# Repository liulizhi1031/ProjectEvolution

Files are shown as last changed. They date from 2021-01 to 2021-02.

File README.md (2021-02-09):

# ProjectEvolution
## 一款航模/无人机/机器人遥控器  
## A RC/Drone/Robot Controler   

### 一.项目进展

#### &emsp;2021年2月9日

&emsp;目前本项目已完成初版PCB和外壳设计，马上开始软件开发阶段。（为了节省材料，外壳有点惨不忍睹，，，，）

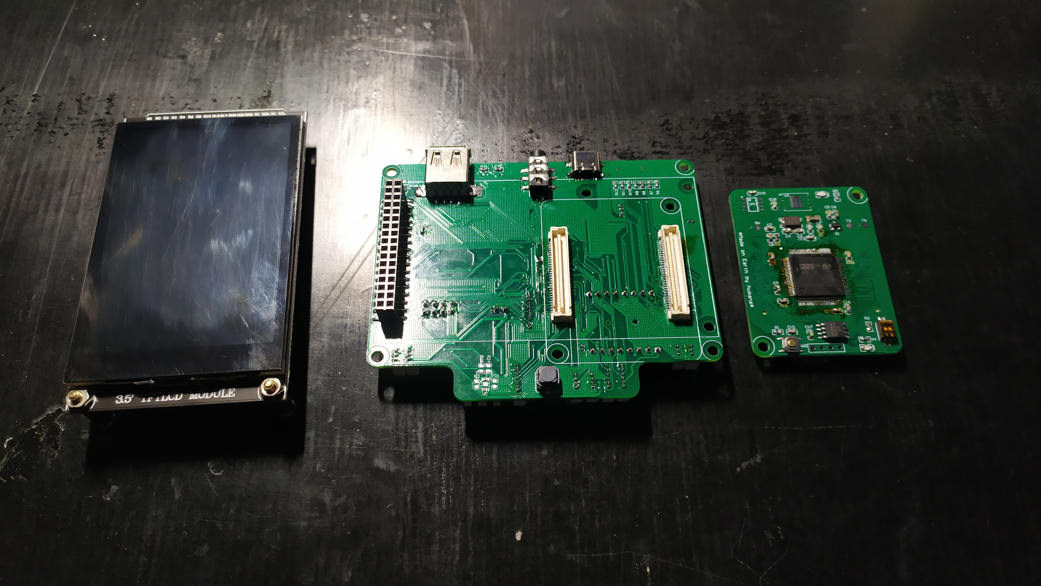
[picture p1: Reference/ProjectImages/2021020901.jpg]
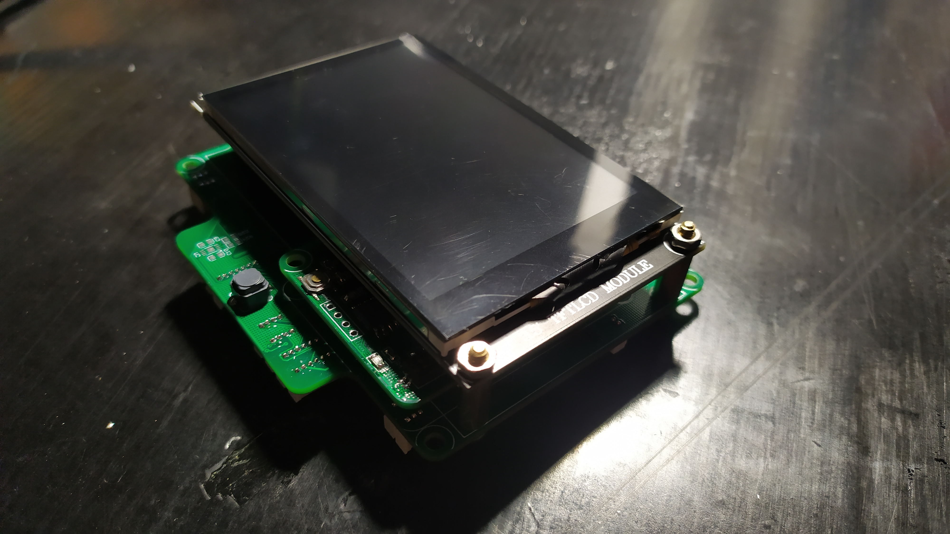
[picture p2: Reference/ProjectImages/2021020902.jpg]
 

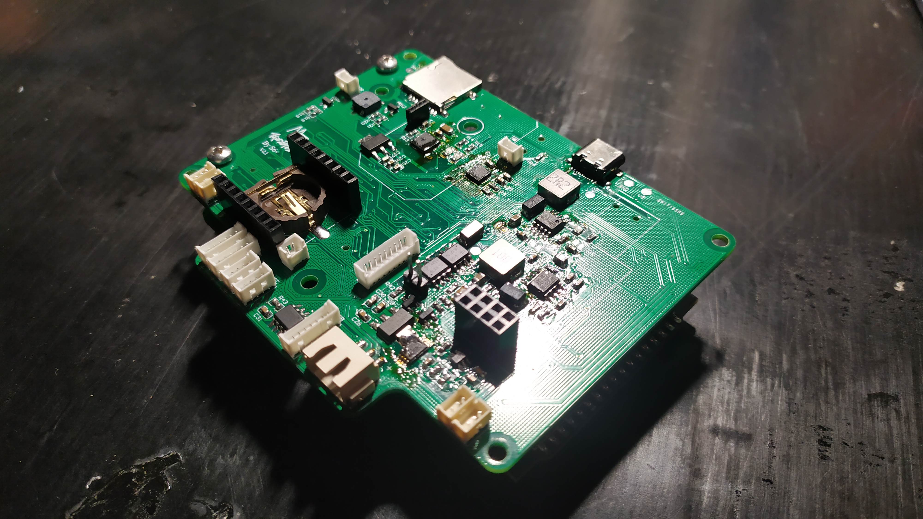
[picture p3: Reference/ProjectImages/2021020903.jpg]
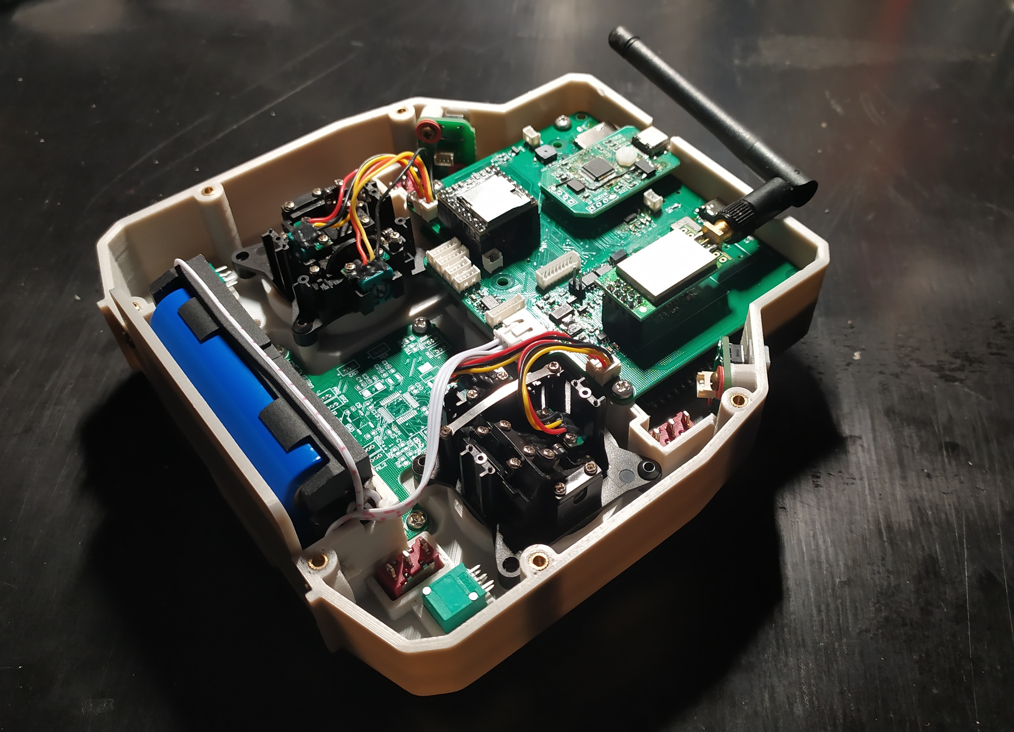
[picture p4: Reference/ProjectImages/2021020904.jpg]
 

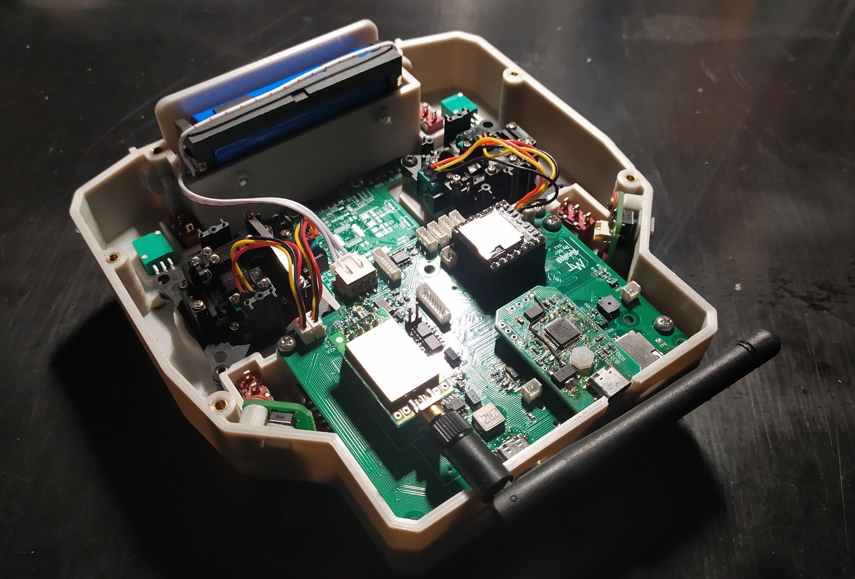
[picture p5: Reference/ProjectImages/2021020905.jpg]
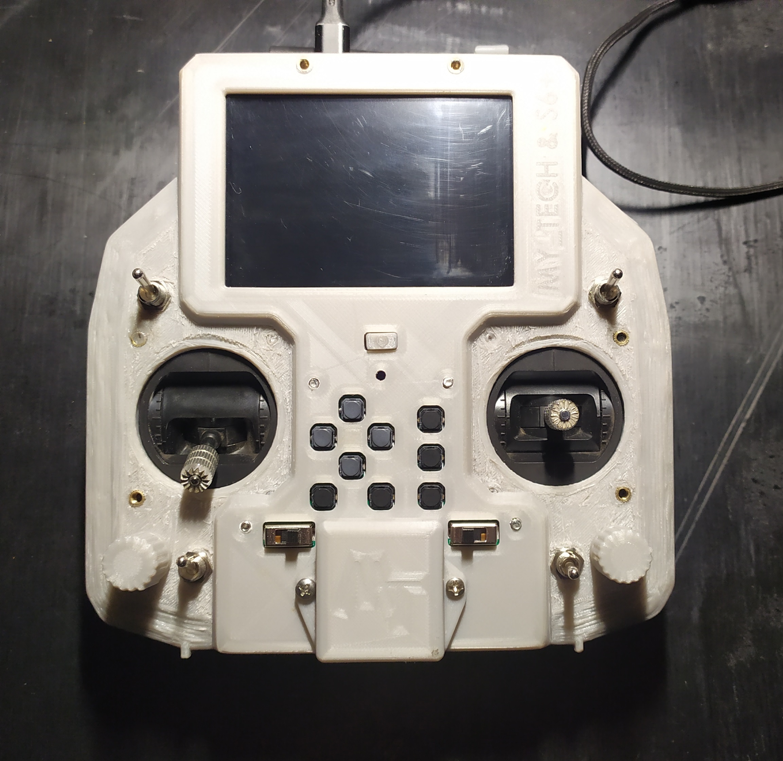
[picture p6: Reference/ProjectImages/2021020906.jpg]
 

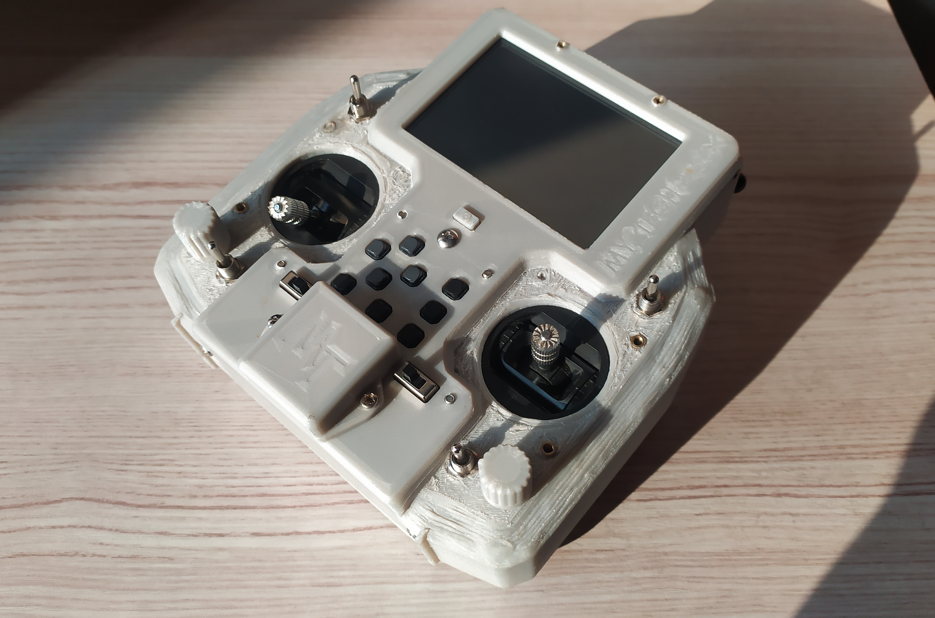
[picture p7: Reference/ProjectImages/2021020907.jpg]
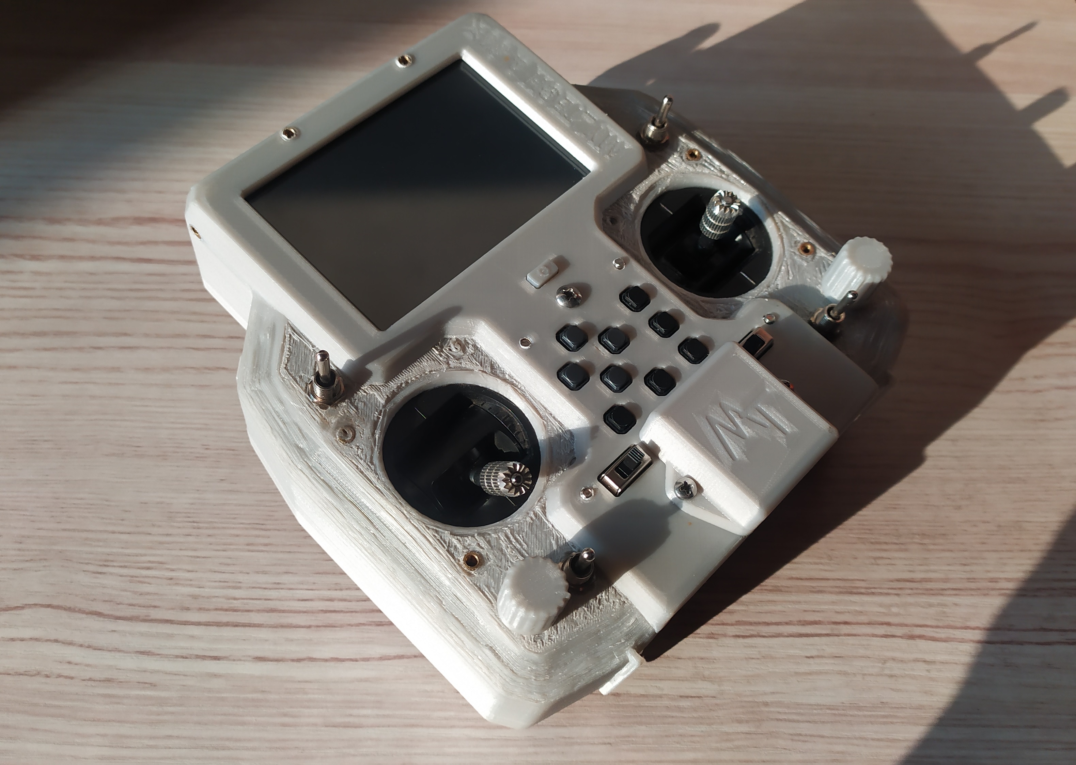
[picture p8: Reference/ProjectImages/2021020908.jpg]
 

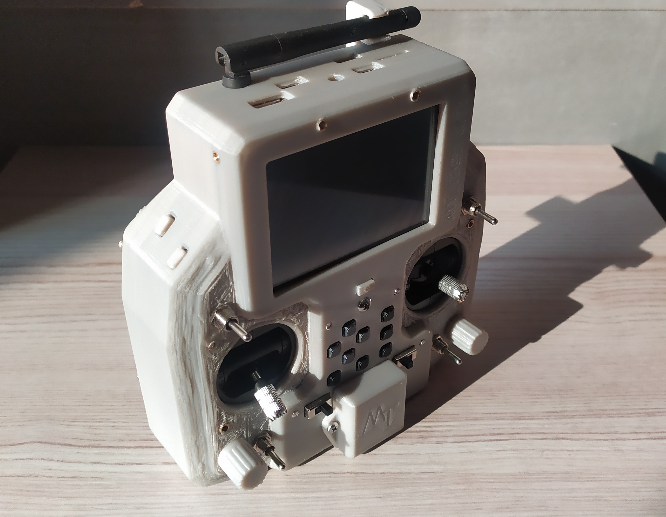
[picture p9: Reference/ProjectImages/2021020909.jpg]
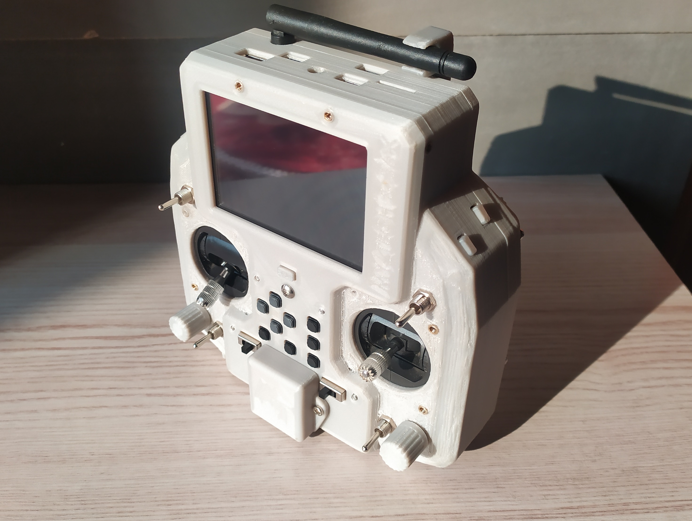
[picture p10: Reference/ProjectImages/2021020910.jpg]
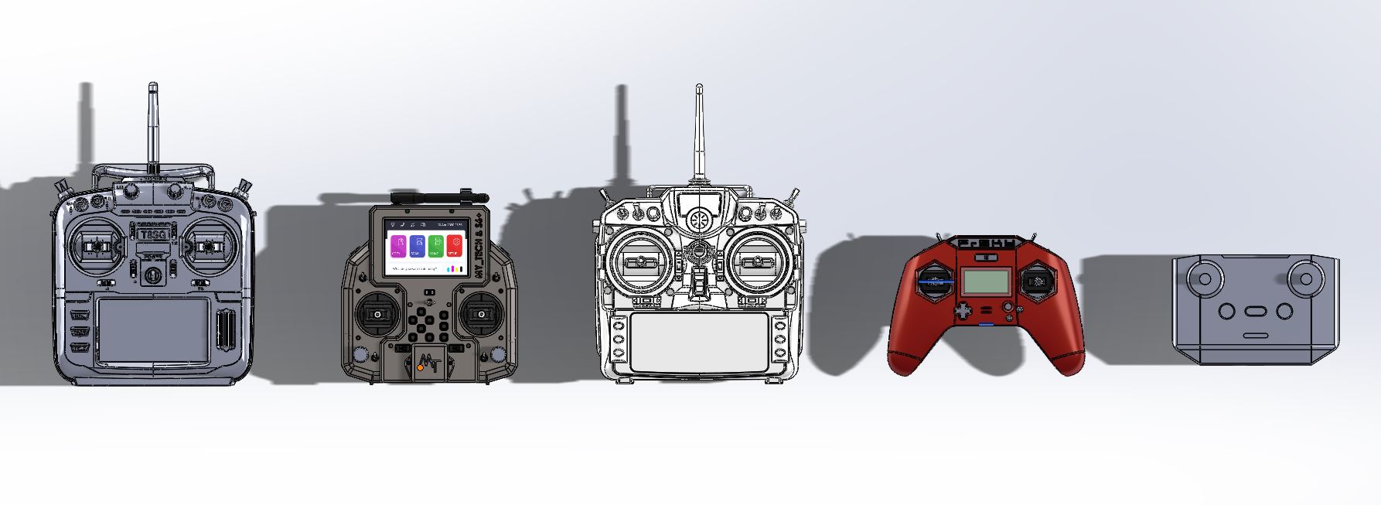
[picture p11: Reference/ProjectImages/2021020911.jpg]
 

### 二.项目简介

&emsp;本项目起始于2020年底，但追溯起来，我个人自制遥控器可以一直延伸到2016年左右。2015年由于资金和安全等原因，我放弃了自制火箭项目，转而玩多旋翼无人机，当时的大疆还是一颗争议不断的新星，Doby无人机正在火热众筹，我正即将从高中毕业，也正在自学Arduino。相比火箭，多旋翼使用成本几乎可以忽略不计，安全性也大大提高，但放在我眼前的第一件事就是遥控器的选择。  
&emsp;多旋翼无人机是从航模的基础上发展而来技术，因此当时大多数自制无人机也都采用成品航模遥控器，然而对于一个四线城市的农村高中生来说，即使是富斯i6也让我觉得太贵了，更何况越是便宜的遥控器，功能就越简陋，更难以让我这个轻度强迫症患者接受。既然好的买不起，买得起的又太渣，那干脆就自己做吧。我没有想到的是这个坑到现在我还没有填上，，，，，  
&emsp;我的第一套自制的遥控系统是在2016年暑假完成的，样子相当简陋，但还是用了模块化的设计，主控是Arduino nano，遥控器分为左右摇杆模块、显示模块、核心模块，可以组合成极简模式和完全体模式。     

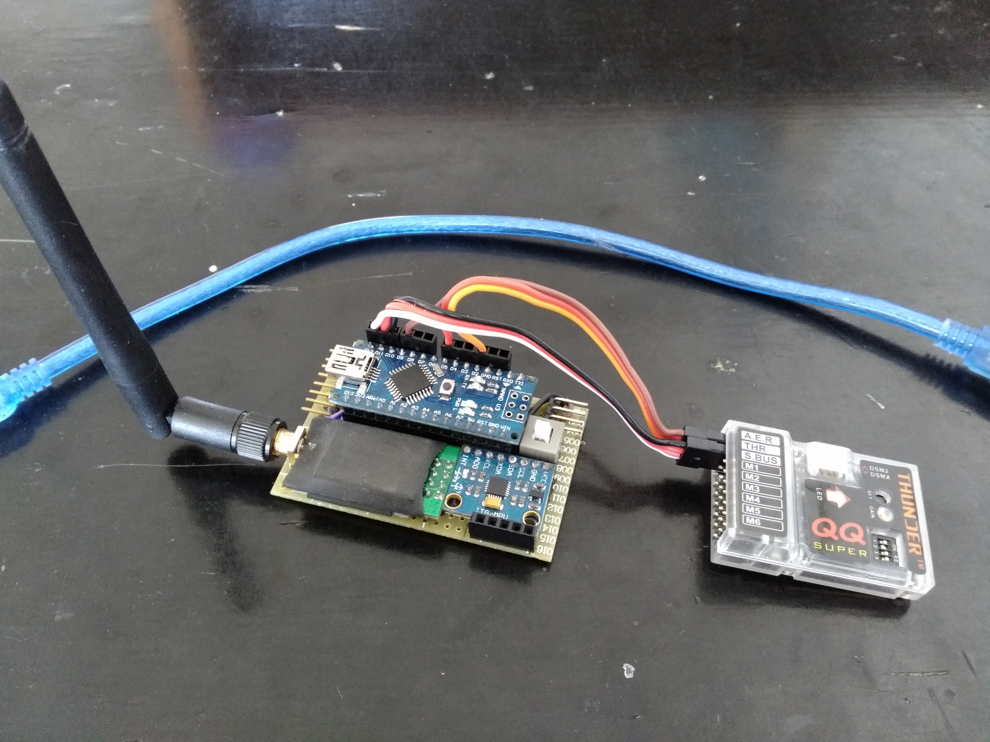
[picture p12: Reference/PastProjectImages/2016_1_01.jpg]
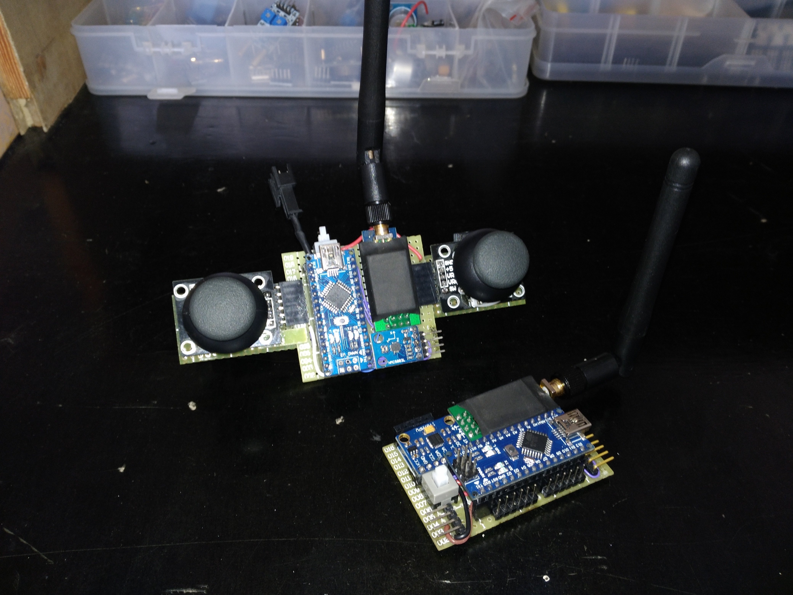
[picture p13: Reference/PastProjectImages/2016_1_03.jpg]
 

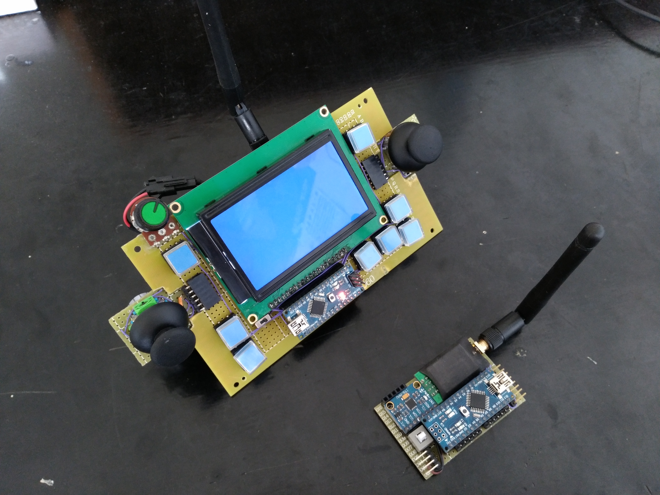
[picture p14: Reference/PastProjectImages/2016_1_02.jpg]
 

 &emsp;2016年9月，我进入河北科技大学，成为飞行器设计与工程专业的首批学生，一个月以后我加入了电气学院409实验室（大学生创新素能基地）接着填我的坑。我使用了3块Arduino nano以满足功能需要，分别负责显示、数据读取、通信和数据处理。然而结果是惨烈的，Arduino孱弱的性能根本无法支撑如此的野心，只有STM32才能救项目！      

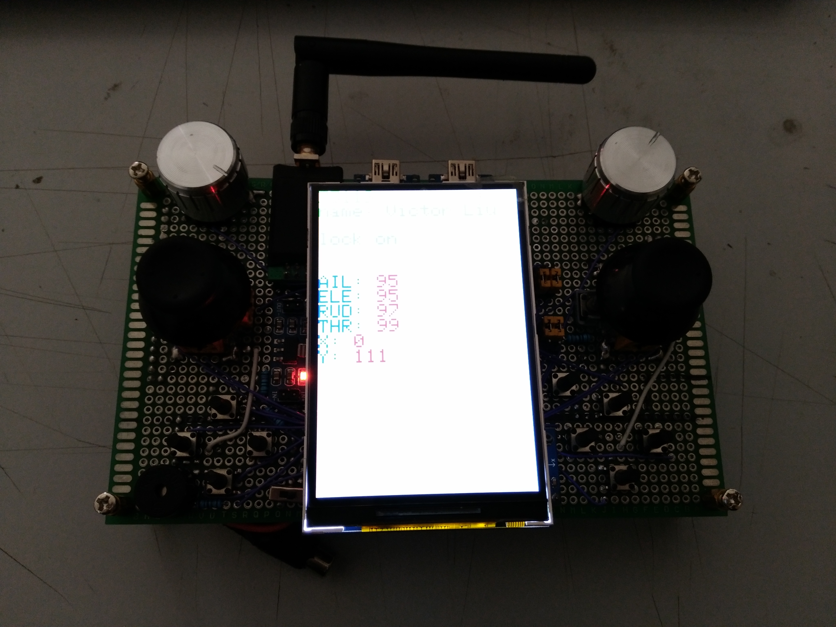
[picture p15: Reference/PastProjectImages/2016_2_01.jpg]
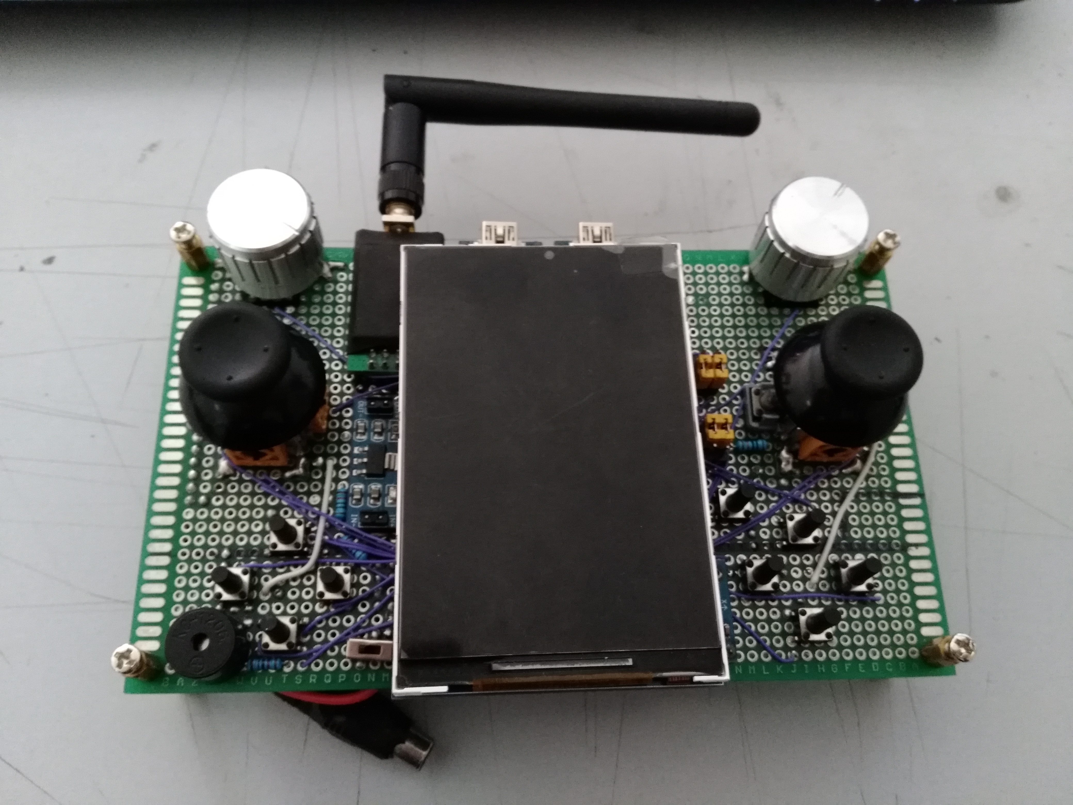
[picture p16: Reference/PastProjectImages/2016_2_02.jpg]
 

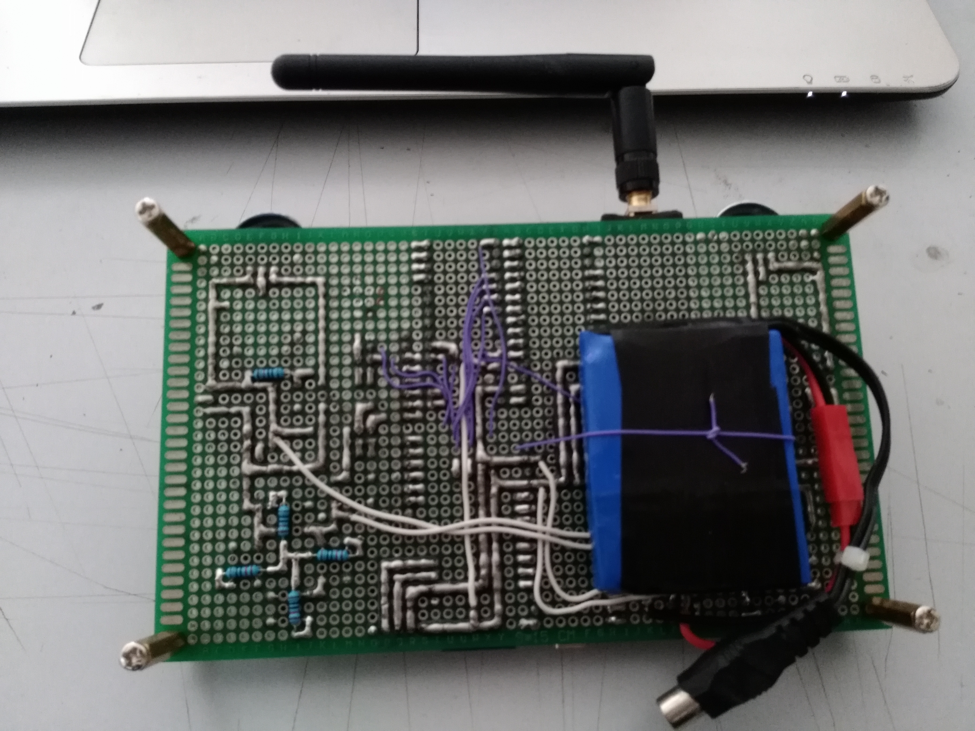
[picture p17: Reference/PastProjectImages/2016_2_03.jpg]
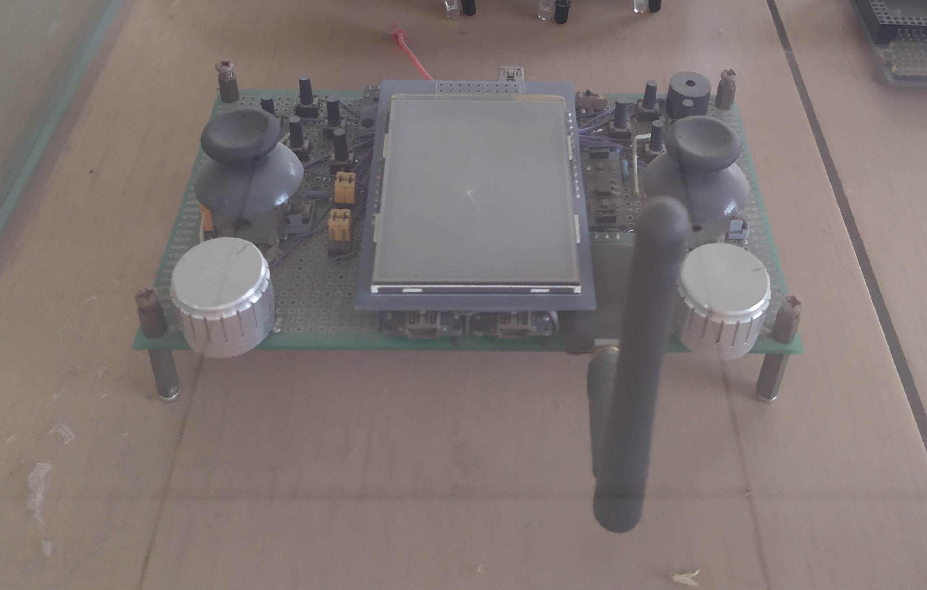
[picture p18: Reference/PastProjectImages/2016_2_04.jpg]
  

&emsp;接下来开始学习研究STM32，我发现F1和F4的学习难度几乎相同，因而直接上到STM32F407VET6，屏幕使用电阻触摸屏，然而做到一半我发现我的板子被焊成了假发，密密麻麻的飞线无不触发我的强迫症，因此学习PCB绘制看来是下一个必须解决的问题。    

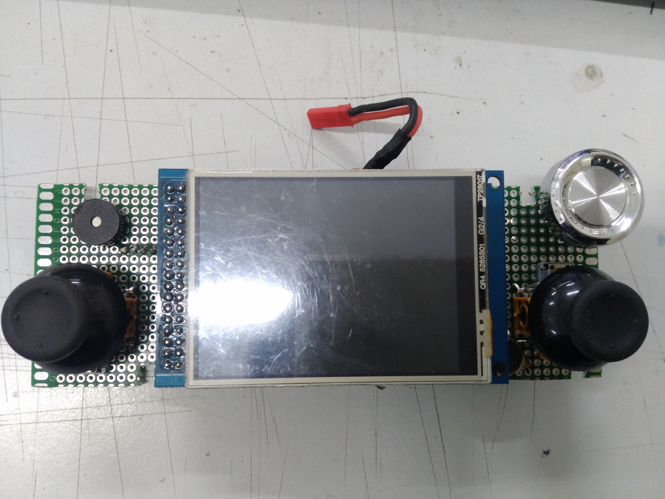
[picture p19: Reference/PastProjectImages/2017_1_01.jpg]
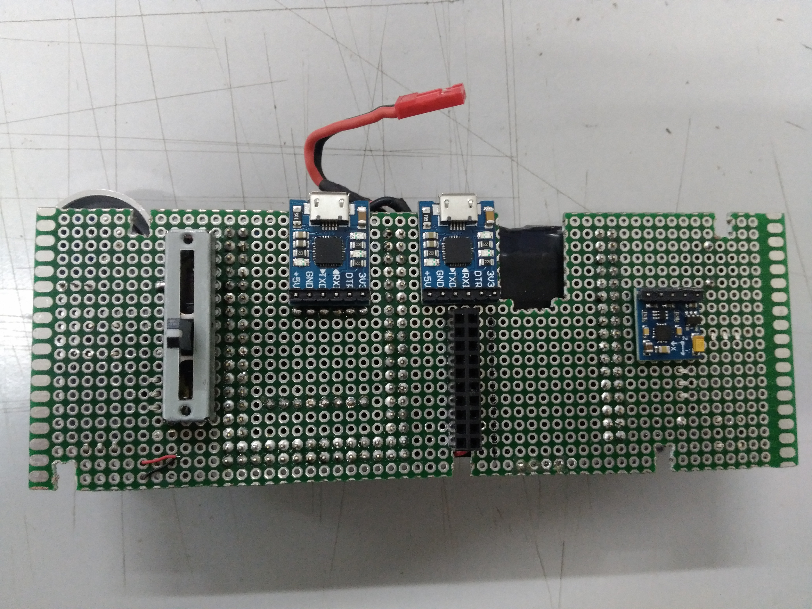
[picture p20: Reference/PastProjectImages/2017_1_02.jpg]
  

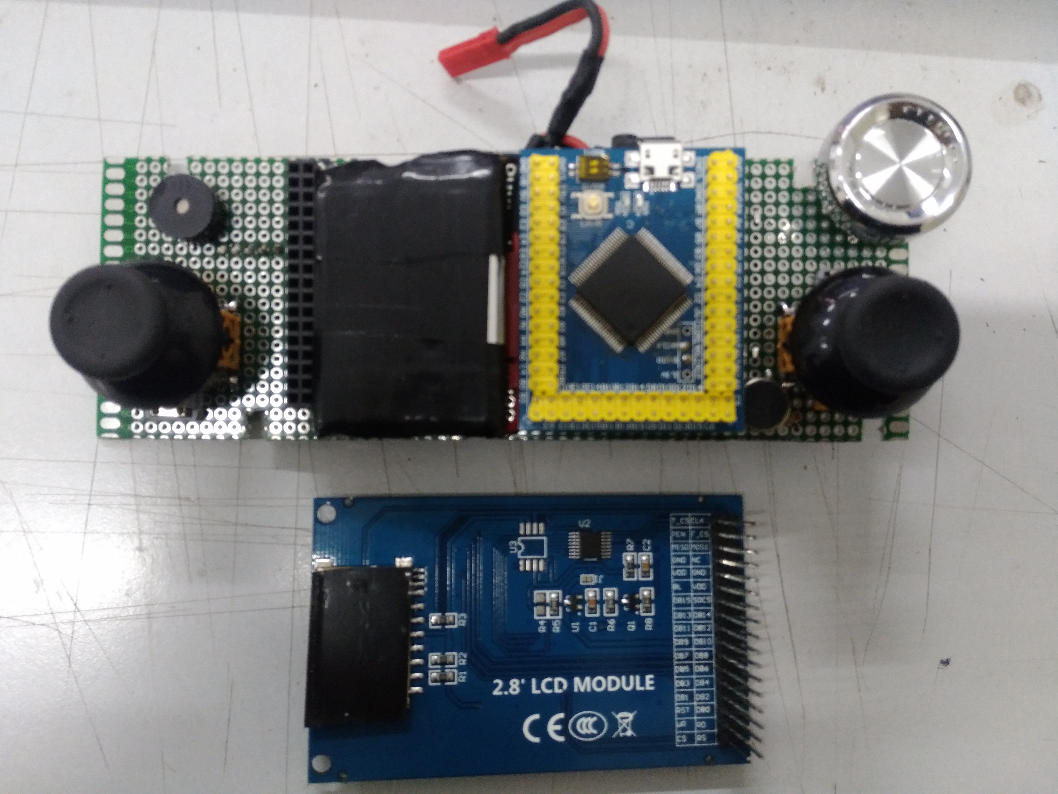
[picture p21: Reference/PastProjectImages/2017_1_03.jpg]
 

&emsp;与此同时我申报了大学生创新训练项目，虽然只拿到了校级，但顺便拿个名头也还不错了。由于此时我还在航模协会摸鱼，因此也学到了CAD和SolidWorks，接下来就是用STM32、AD、CAD来给这个项目做个了断了。虽然项目结了题，但是我对这套硬件并不满意，亚克力的外壳极为脆弱又搁手，体积虽然比我当时用的AT9小的多，但显然我馋了刚刚发布的大疆Mavic遥控器的身子，因此我又开启了新的征途。    

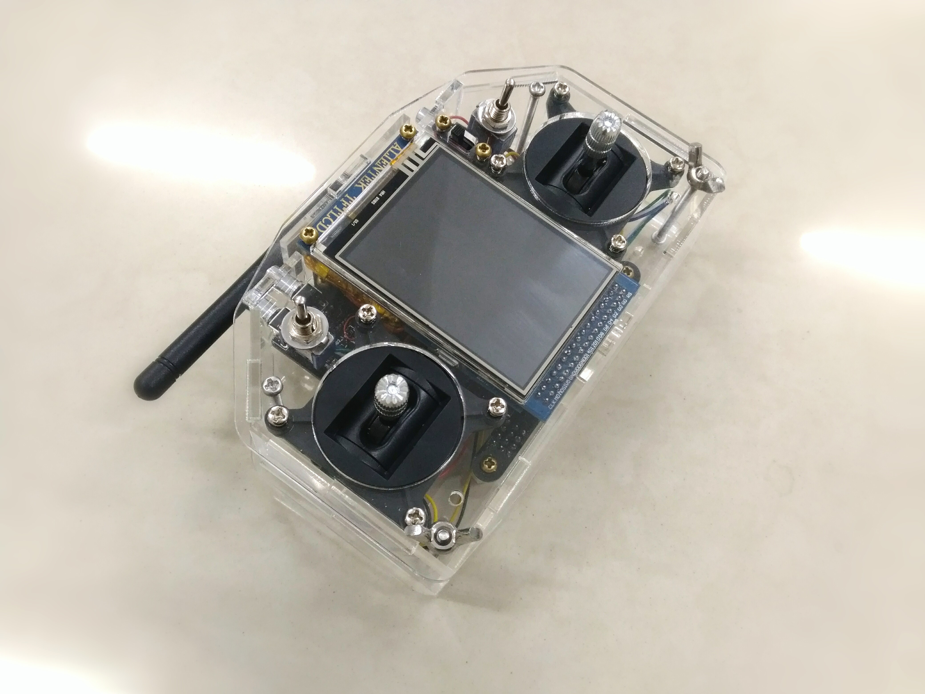
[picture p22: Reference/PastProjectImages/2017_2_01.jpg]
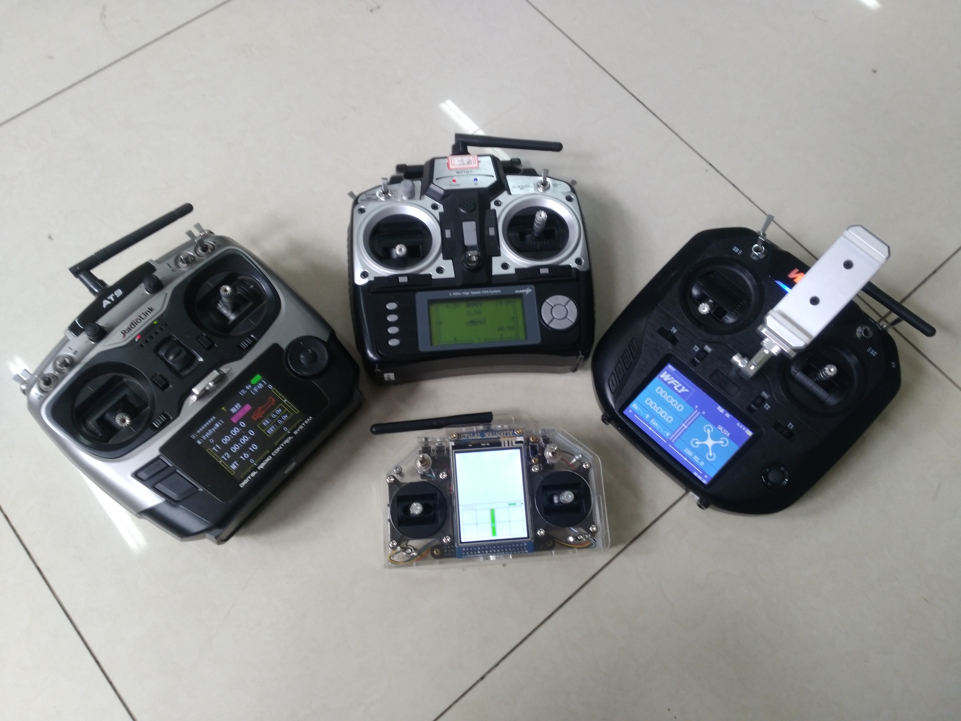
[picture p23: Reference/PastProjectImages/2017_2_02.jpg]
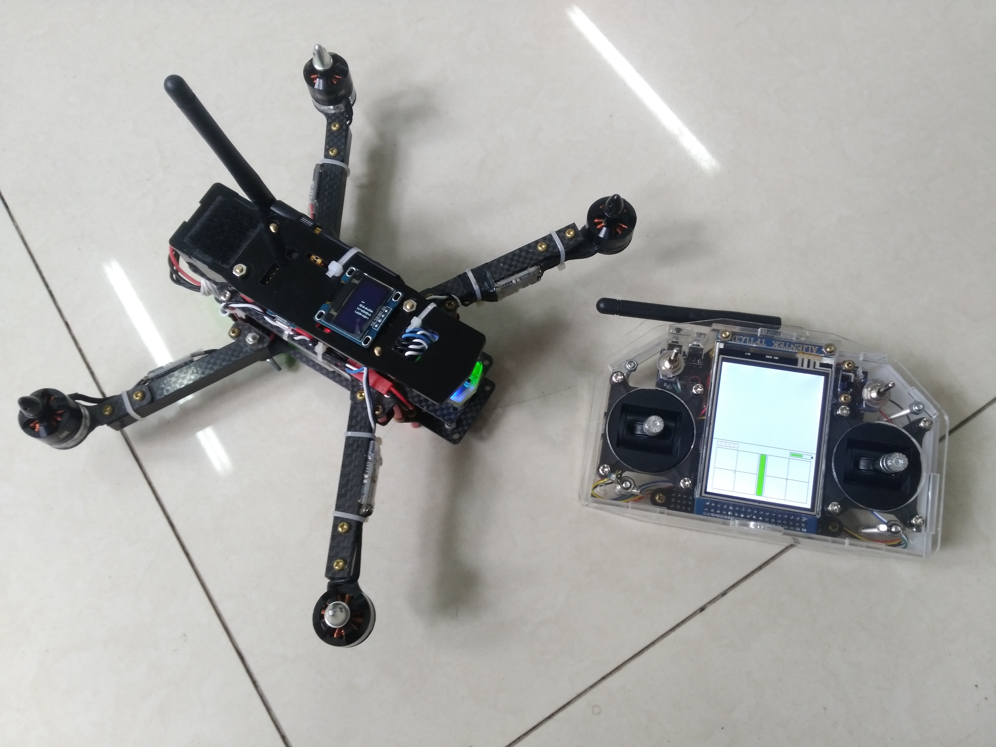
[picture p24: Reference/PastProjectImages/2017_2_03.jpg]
   

&emsp;这次为了更加紧凑，使用了游戏机摇杆（这显然是个致命缺陷），主控STM32F405RGT6直接贴在PCB上，屏幕也缩水到1.8寸（又一个致命缺陷）。一个偶然的机会我发现网上的3D打印服务还不错，而实验室申请的3D打印机一直久批不下，因而只能从网上找平台了，不得不说，光固化真香。总的来看，此时的遥控器和最初的遥控器早已天差地别，但距离成品和我的预期还差的远。    

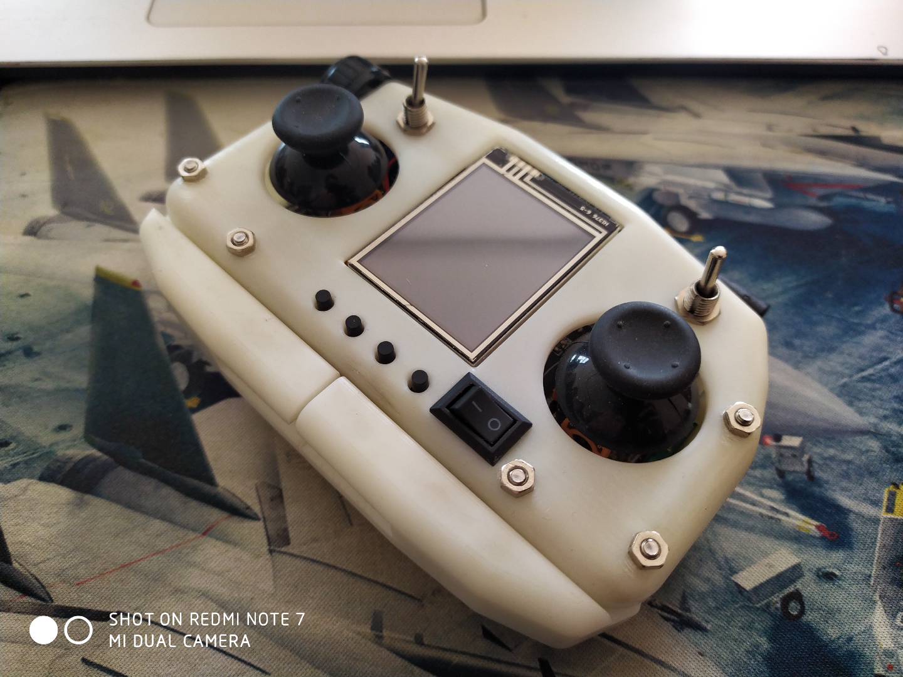
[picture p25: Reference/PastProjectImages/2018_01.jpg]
 

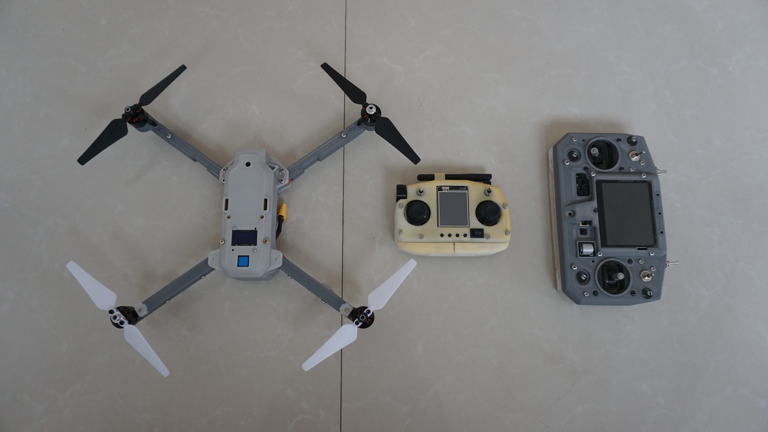
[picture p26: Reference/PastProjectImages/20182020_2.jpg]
&emsp;接下来的一年就是准备考研，但显然我高估了自己对考试的忍耐程度，直到2020年初，打着毕设的幌子，我重新开始填坑，这次希望能让遥控器更加成熟吧。毕设的进度催促着我要把重心向着多旋翼端偏移，这个控也仅仅完成了硬件的初步设计，软件更是只建了个文件夹。当然暴露的问题也不少，包括由于屏幕中置使遥控器过宽、过于集中化的PCB设计使试错成本猛增、握持手感极差等等一系列细节问题。    

&emsp;时间来到现在，2020年我一直在准备考研二战，一年的闭关修炼差点直接把我送走，还好这一切都在它该结束的时刻结束了。虽然考试凉了，但坑还是要接着填啊。为了方便和志同道合的朋友们交流心德，也是为了督促自己减少去安东星摸鱼的时间，我决定把项目公开出来。后排提醒，PCB线布的贼乱、代码bug更多，大佬轻喷。  
&emsp;目前项目取名为“进化”，计划使用STM32H750VBT6作为主控（性价比高），STM32F103C8T6作为协处理器（主控IO太少），3.5寸电容触摸屏（性价比高），固件基于FreeRTOS（文件夹还没建），界面基于LVGL，兼容主流航模遥控器高频头，自带通信模块仍是NRF24L01，但预留扩展接口，稍微遗憾的是由于H750的IO太少，音乐播放只能使用独立的MP3模块，但也降低了开发难度，算是一个取舍吧。  
&emsp;目前项目正在进行中，感兴趣的朋友们欢迎持续关注，可以关注我的bilibili账号“我的科技工作室”交流。 20210128

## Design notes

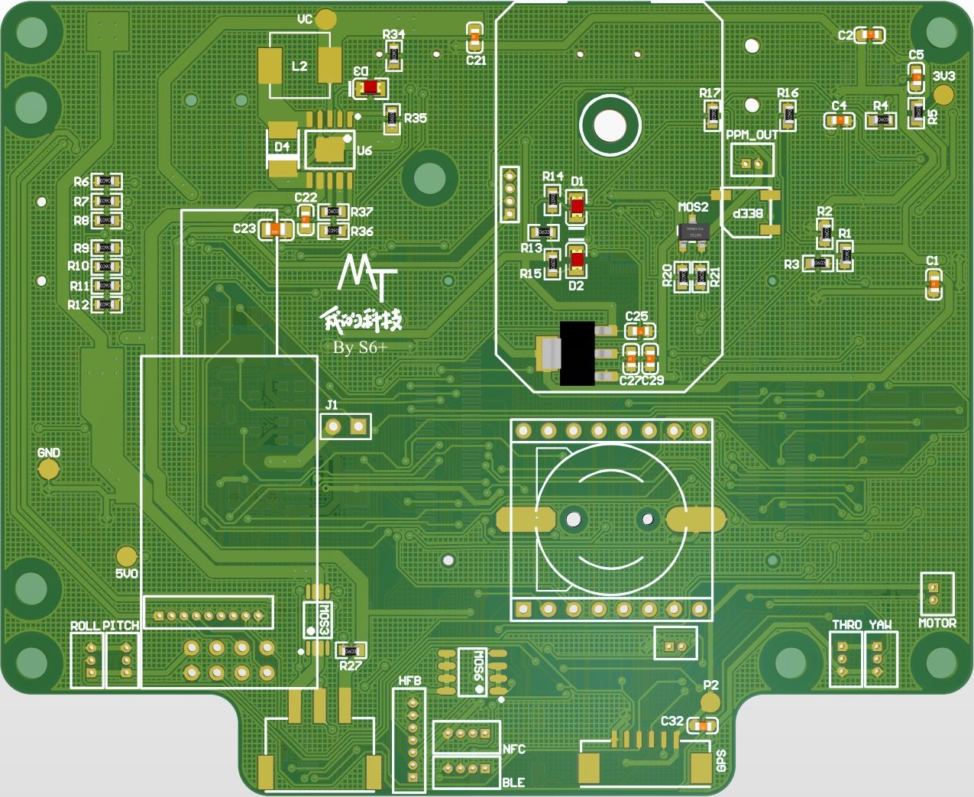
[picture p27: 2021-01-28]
3D_Model/V0.1_3D_Model/picture/baseboard2.JPG

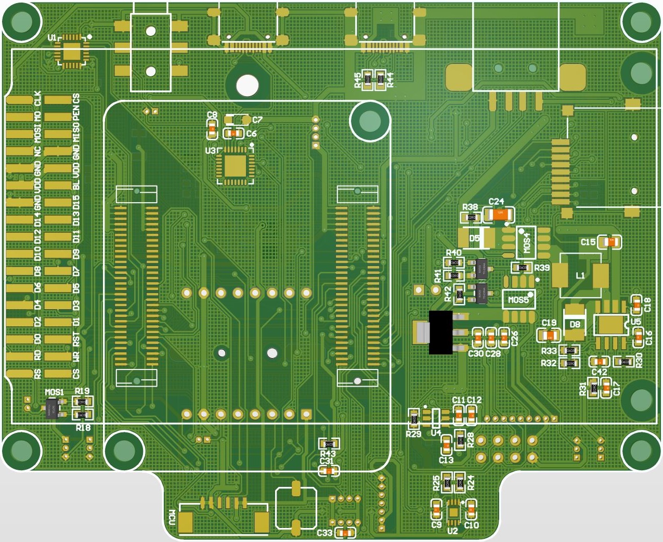
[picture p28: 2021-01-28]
3D_Model/V0.1_3D_Model/picture/baseboard1.JPG

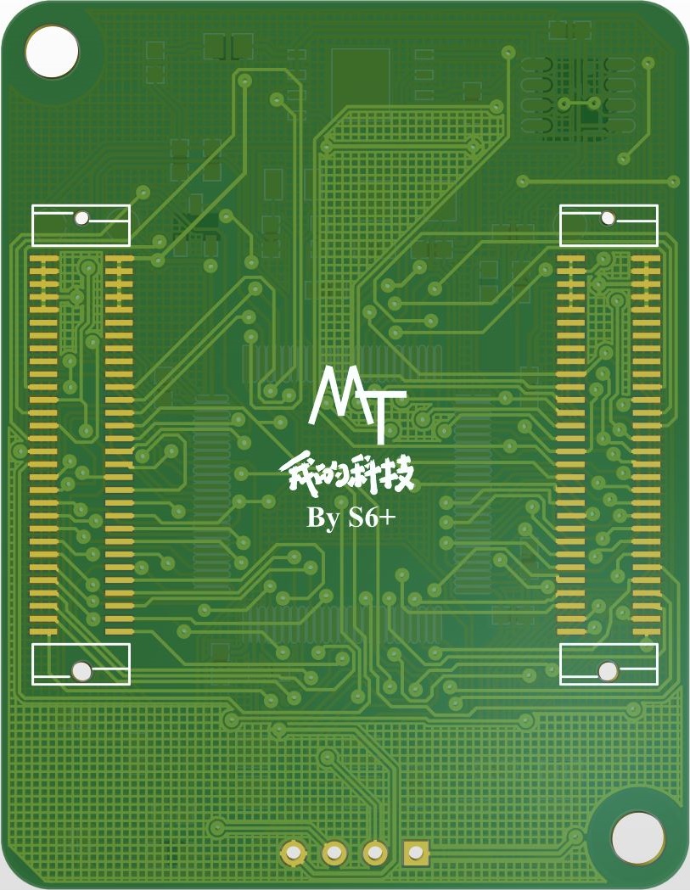
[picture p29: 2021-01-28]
3D_Model/V0.1_3D_Model/picture/coreboard2.JPG

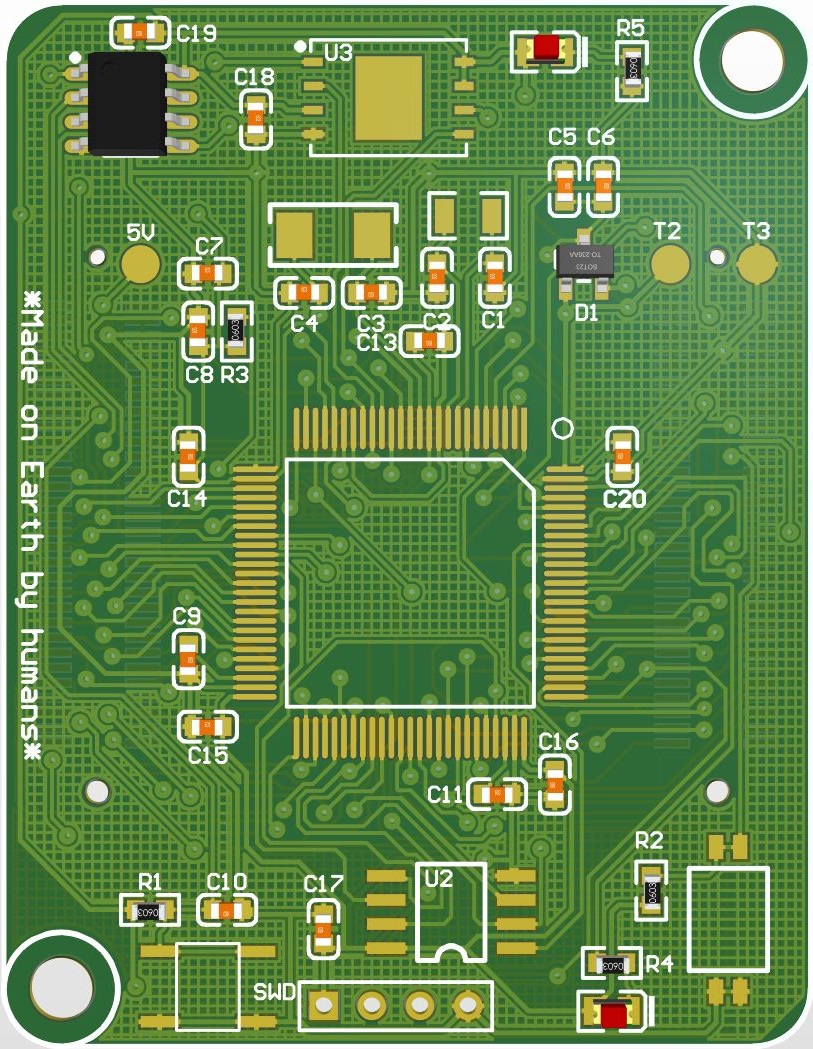
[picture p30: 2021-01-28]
3D_Model/V0.1_3D_Model/picture/coreboard1.JPG

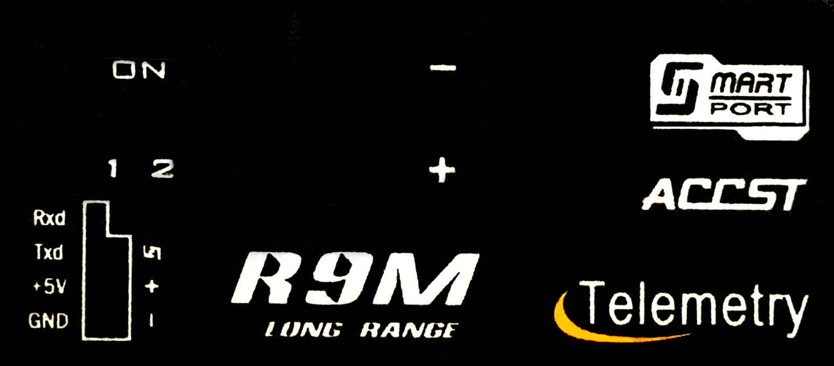
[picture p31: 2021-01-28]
3D_Model/V0.1_3D_Model/Frsky-R9M/TEXT_R9M.jpg

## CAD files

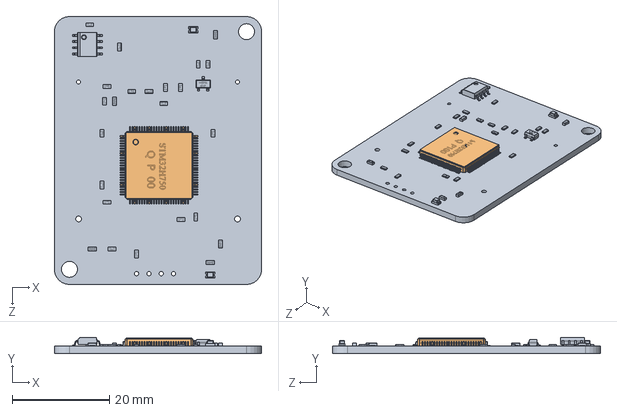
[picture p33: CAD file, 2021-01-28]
3D_Model/V0.1_3D_Model/coreboard/COREBOARD.SLDASM
42.8 x 3.34 x 55.3 mm
coreboard
STM32H750VBT6

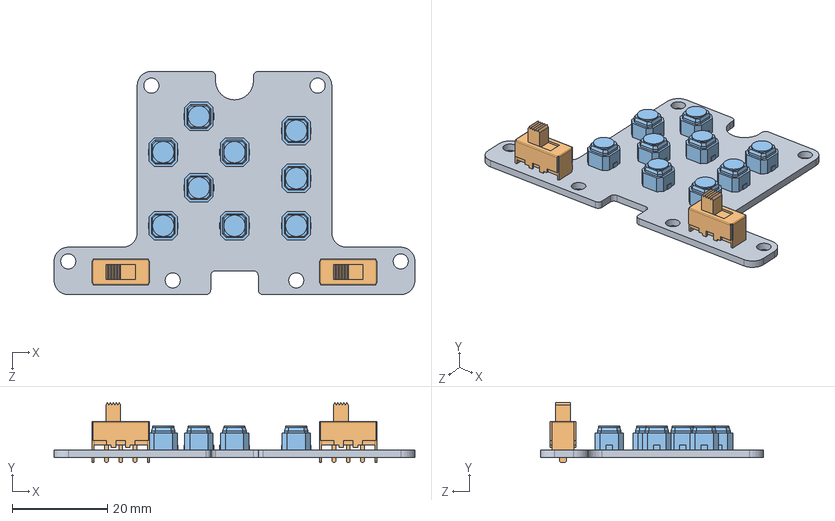
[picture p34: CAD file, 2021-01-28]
3D_Model/V0.1_3D_Model/keyboard/KEYBOARD.SLDASM
76.0 x 12.7 x 47.0 mm
KEYBOARD
滑动开关 x 2
静音按键_ x 9

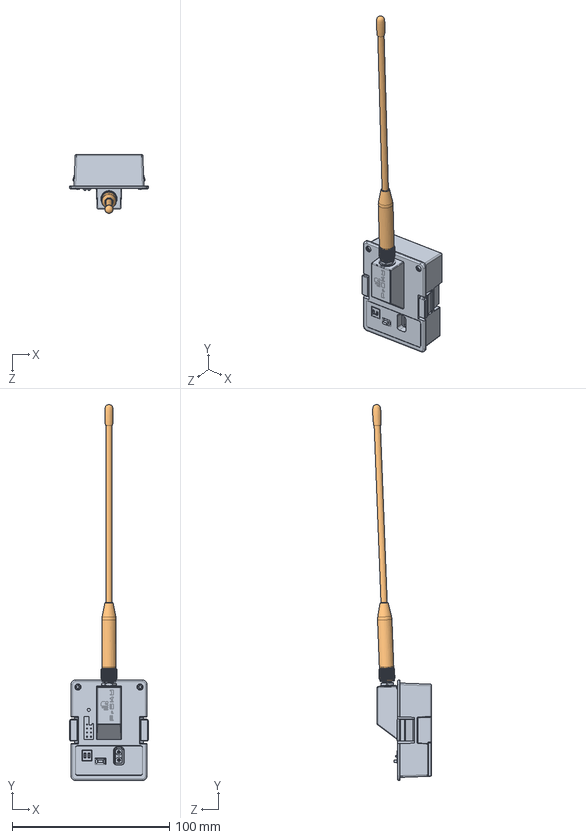
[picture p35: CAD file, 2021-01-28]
3D_Model/V0.1_3D_Model/Frsky-R9M/R9M_ASM.SLDASM
50.0 x 239.0 x 37.4 mm
FrSky_R9M
ANTENNE_R9M_LongRange

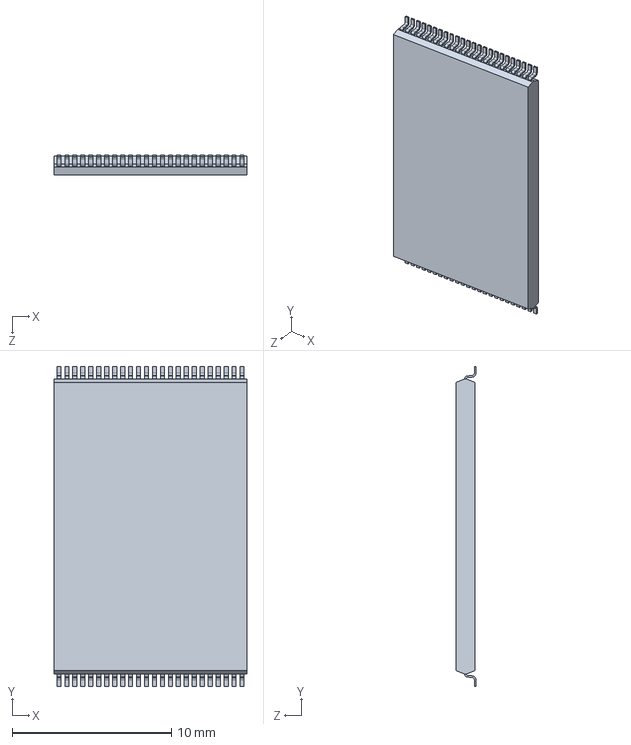
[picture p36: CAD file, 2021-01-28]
3D_Model/V0.1_3D_Model/SWD模块/AMS1117-3.3V/TSOP48.step.SLDASM
12.1 x 20.1 x 1.26 mm

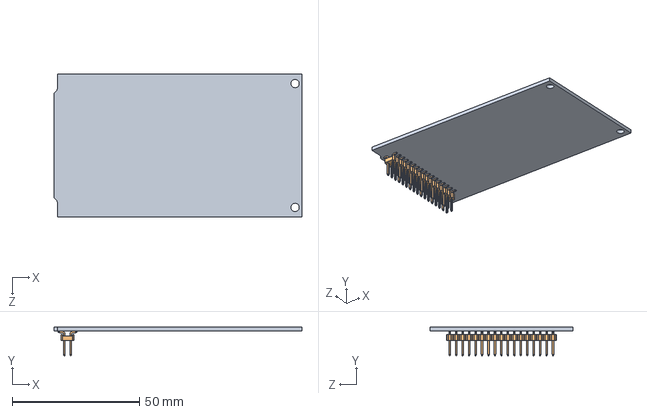
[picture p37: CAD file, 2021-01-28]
3D_Model/V0.1_3D_Model/3.5寸屏幕模块/3.5_LCD.SLDASM
97.6 x 11.3 x 56.4 mm
MRB3511_LCD_MODULE
PIN254 x 17

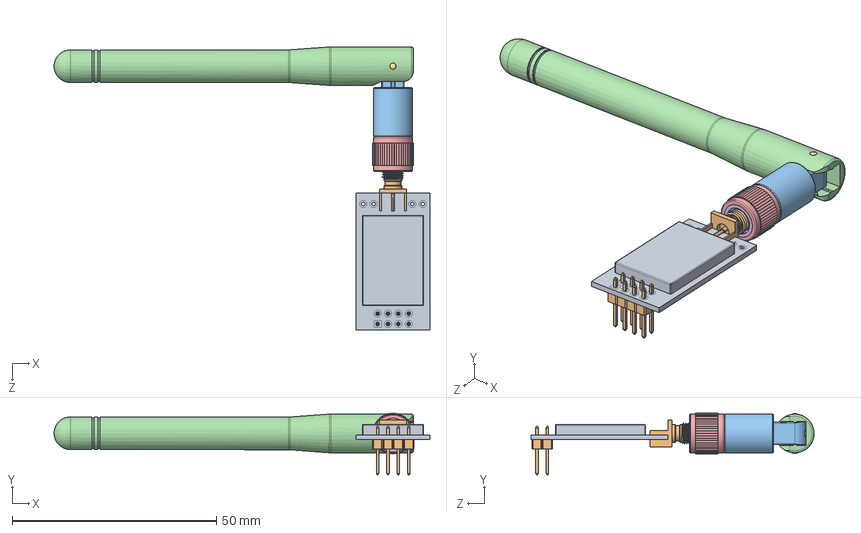
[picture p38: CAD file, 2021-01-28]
3D_Model/V0.1_3D_Model/NRF24l01/NRF24L01.SLDASM
91.9 x 15.1 x 69.3 mm
E01-ML01DP5
Amphenol 132415.step
Bottom_Radio_Antenna
Top_Radio_Antenna
Screw_Radio_Antenna
Insert_Radio_Antenna
Pin_Radio_Antenna x 2
Wire_Top_Radio_Antenna
Wire_Radio_Antenna
2.54MM_4_2PIN

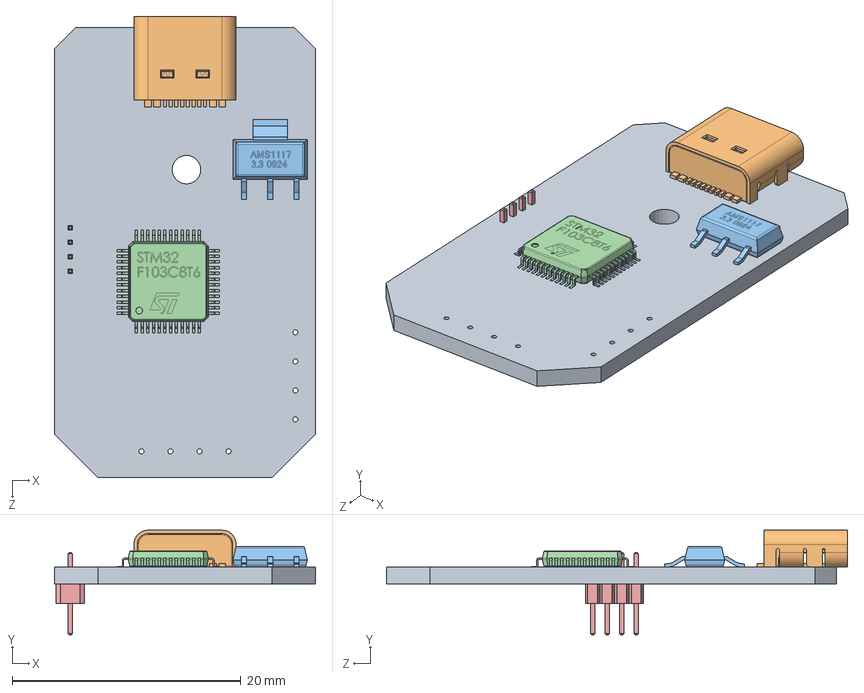
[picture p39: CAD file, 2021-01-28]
3D_Model/V0.1_3D_Model/SWD模块/SWD装配体.SLDASM
22.9 x 9.16 x 40.3 mm
SWD模块
USB Type C Port (SMD Type)
AMS1117
STM32-LQFP48
1.27mmHeader x 4

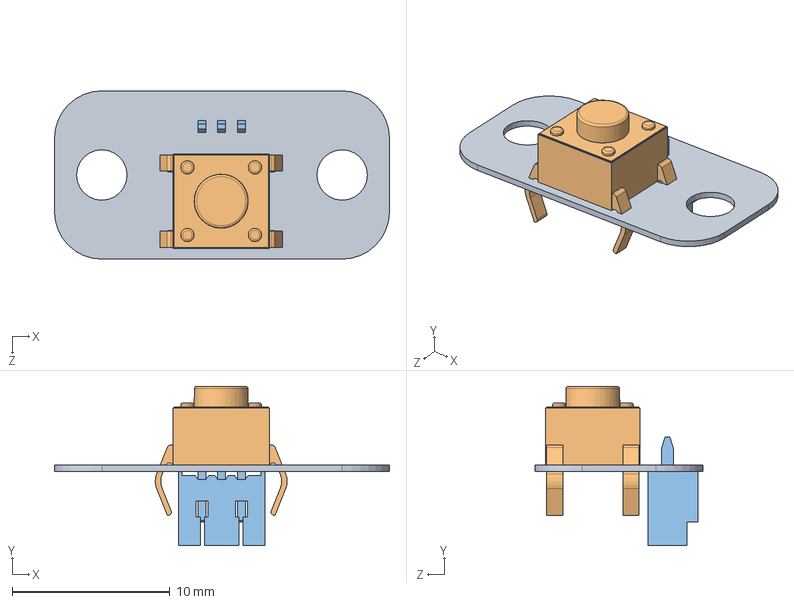
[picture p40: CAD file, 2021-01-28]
3D_Model/V0.1_3D_Model/按键板/KEYL2.SLDASM
21.2 x 10.1 x 10.7 mm
keyL2
Tactal Switch -Thru (6mmx 6mmx5.0mm)
JST connector 1x3

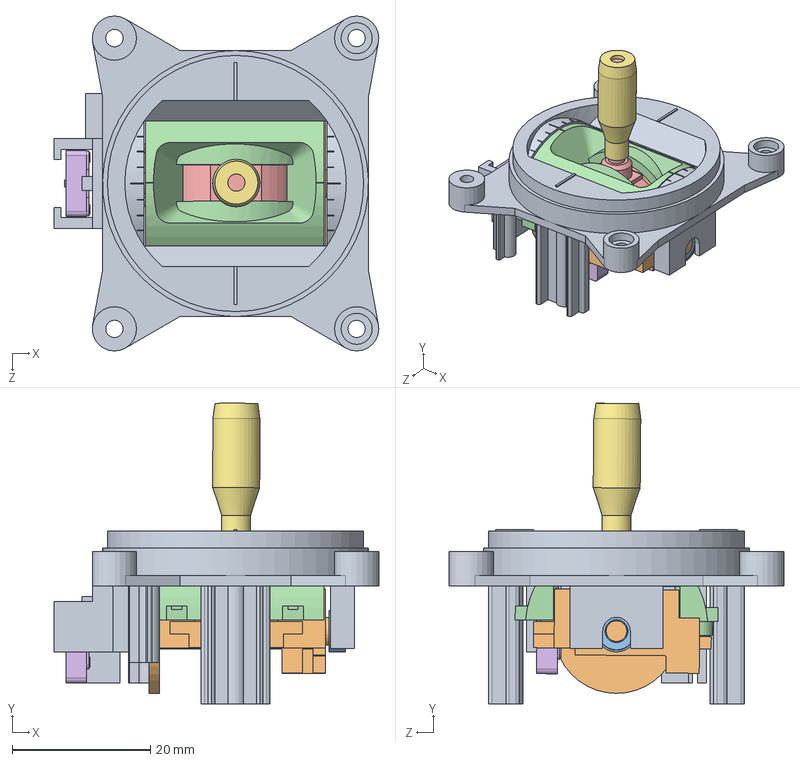
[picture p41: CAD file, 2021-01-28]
3D_Model/V0.1_3D_Model/航模摇杆T8SG/摇杆T8SG装配.SLDASM
46.9 x 43.4 x 48.4 mm
航模摇杆
摇杆中间组件1
轴承 x 4
摇杆中间组件2
摇杆中间组件3
电位器 x 2
摇杆头

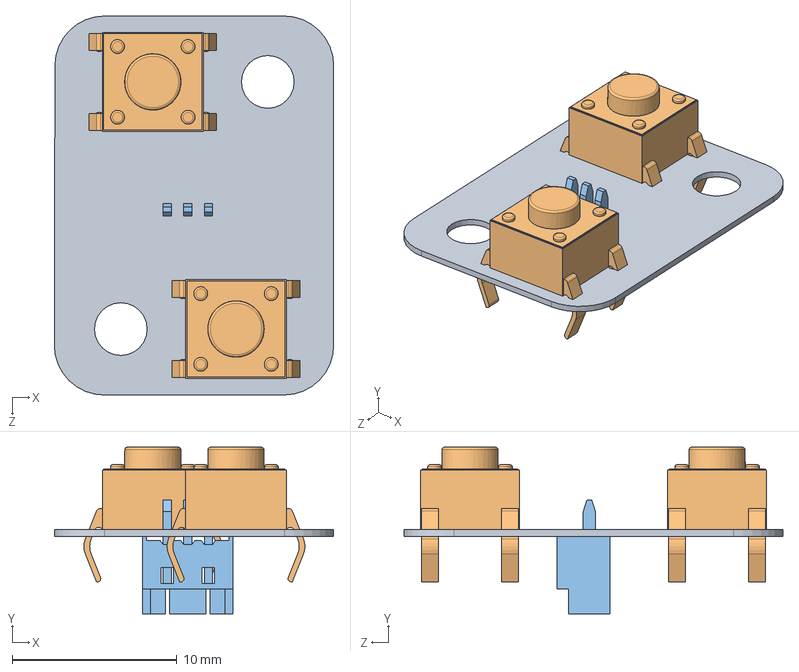
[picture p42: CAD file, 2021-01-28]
3D_Model/V0.1_3D_Model/按键板/KEYR1.SLDASM
17.0 x 10.1 x 23.0 mm
keyR1
Tactal Switch -Thru (6mmx 6mmx5.0mm) x 2
JST connector 1x3

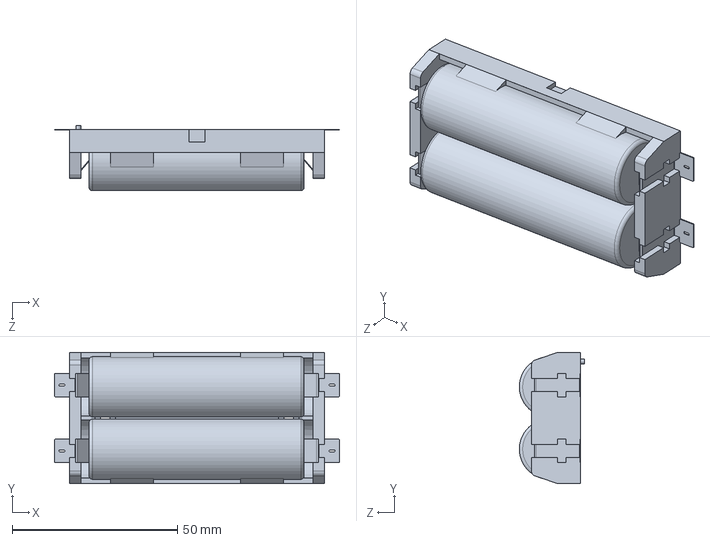
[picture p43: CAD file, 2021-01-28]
3D_Model/V0.1_3D_Model/18650battery/BLM-18650SMT-2.SLDPRT
86.1 x 39.7 x 19.8 mm

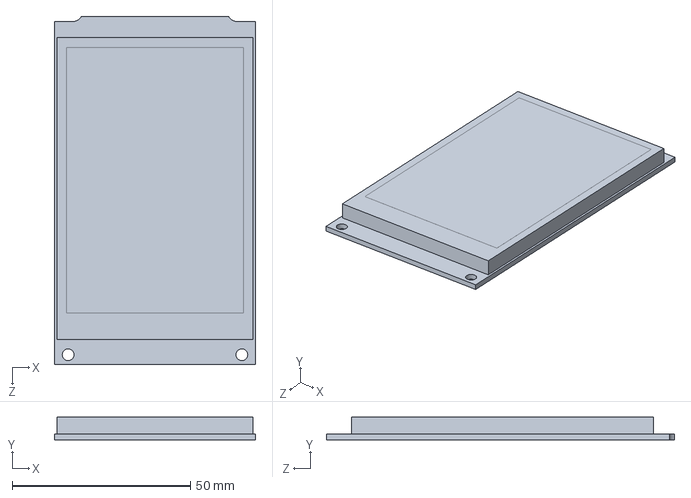
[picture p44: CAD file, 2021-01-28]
3D_Model/V0.1_3D_Model/3.5寸屏幕模块/MRB3511_LCD_MODULE.SLDPRT
56.4 x 6.41 x 97.6 mm

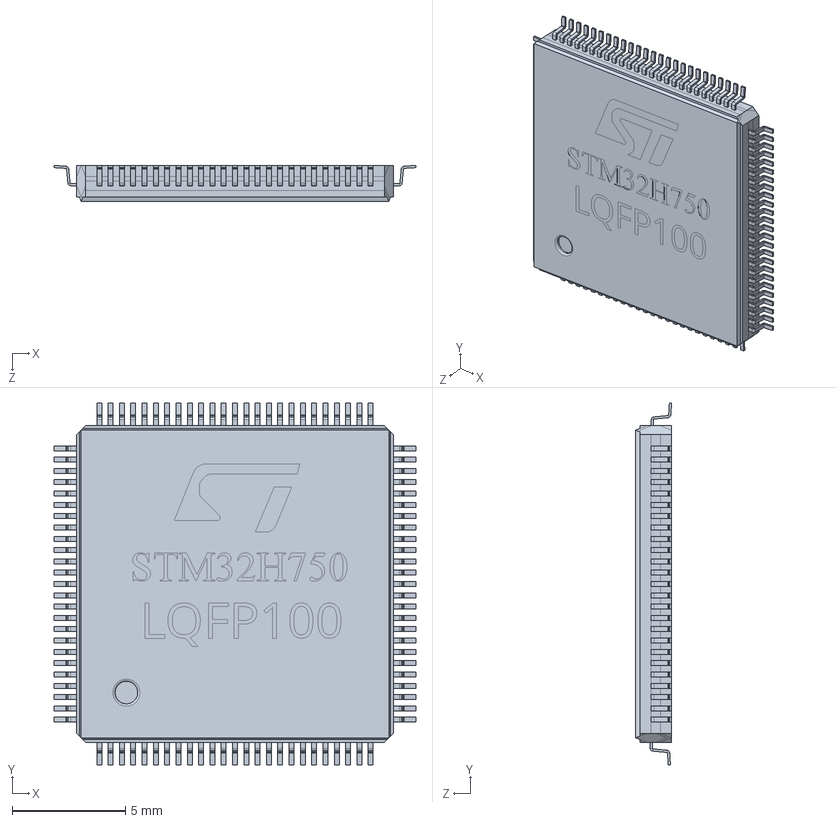
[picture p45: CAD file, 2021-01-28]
3D_Model/V0.1_3D_Model/coreboard/stm32h750vbt6/STM32H750VBT6.SLDPRT
16.0 x 16.0 x 1.60 mm

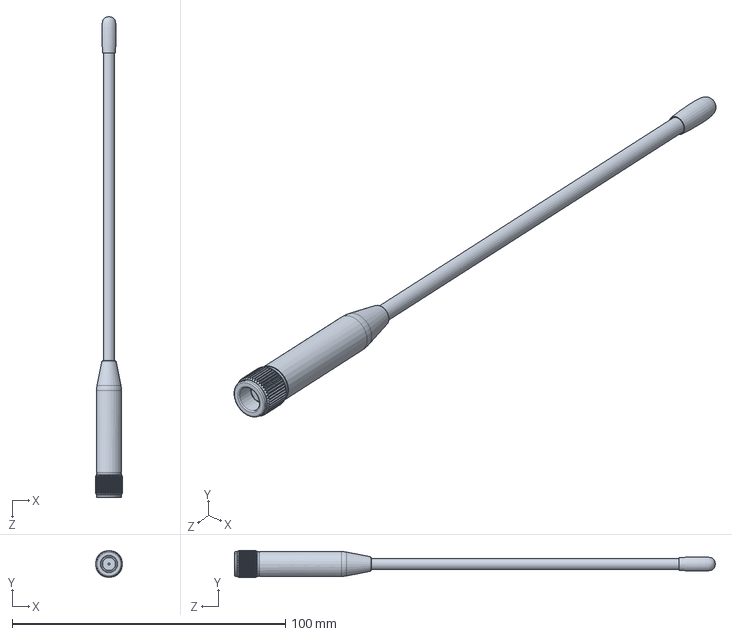
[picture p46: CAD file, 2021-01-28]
3D_Model/V0.1_3D_Model/Frsky-R9M/ANTENNE_R9M_LongRange.SLDPRT
9.99 x 9.99 x 176.1 mm

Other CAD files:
3D_Model/V0.1_3D_Model/按键板/KEYL1.SLDASM
3D_Model/V0.1_3D_Model/按键板/KEYR2.SLDASM
3D_Model/V0.1_3D_Model/GPS-TS100/GPS-TS100.SLDPRT
3D_Model/V0.1_3D_Model/keyboard/滑动开关/滑动开关.SLDPRT
3D_Model/V0.1_3D_Model/3.5寸屏幕模块/PIN254.SLDPRT
3D_Model/V0.1_3D_Model/Frsky-R9M/FrSky_R9M.SLDPRT
3D_Model/V0.1_3D_Model/Frsky-R9M/R9M_ASM.x_t
3D_Model/V0.1_3D_Model/GPS外壳.SLDPRT
3D_Model/V0.1_3D_Model/NRF24l01/2.54MM_4_2PIN.SLDPRT
3D_Model/V0.1_3D_Model/NRF24l01/Amphenol 132415.step.SLDPRT
3D_Model/V0.1_3D_Model/NRF24l01/E01-ML01DP5.SLDPRT
3D_Model/V0.1_3D_Model/NRF24l01/NRF24L01.SLDPRT
3D_Model/V0.1_3D_Model/NRF24l01/棒状天线/Antenna.SLDASM
3D_Model/V0.1_3D_Model/NRF24l01/棒状天线/Antenna.STEP
3D_Model/V0.1_3D_Model/NRF24l01/棒状天线/Bottom_Radio_Antenna.SLDPRT
3D_Model/V0.1_3D_Model/NRF24l01/棒状天线/Insert_Radio_Antenna.SLDPRT
3D_Model/V0.1_3D_Model/NRF24l01/棒状天线/Pin_Radio_Antenna.SLDPRT
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

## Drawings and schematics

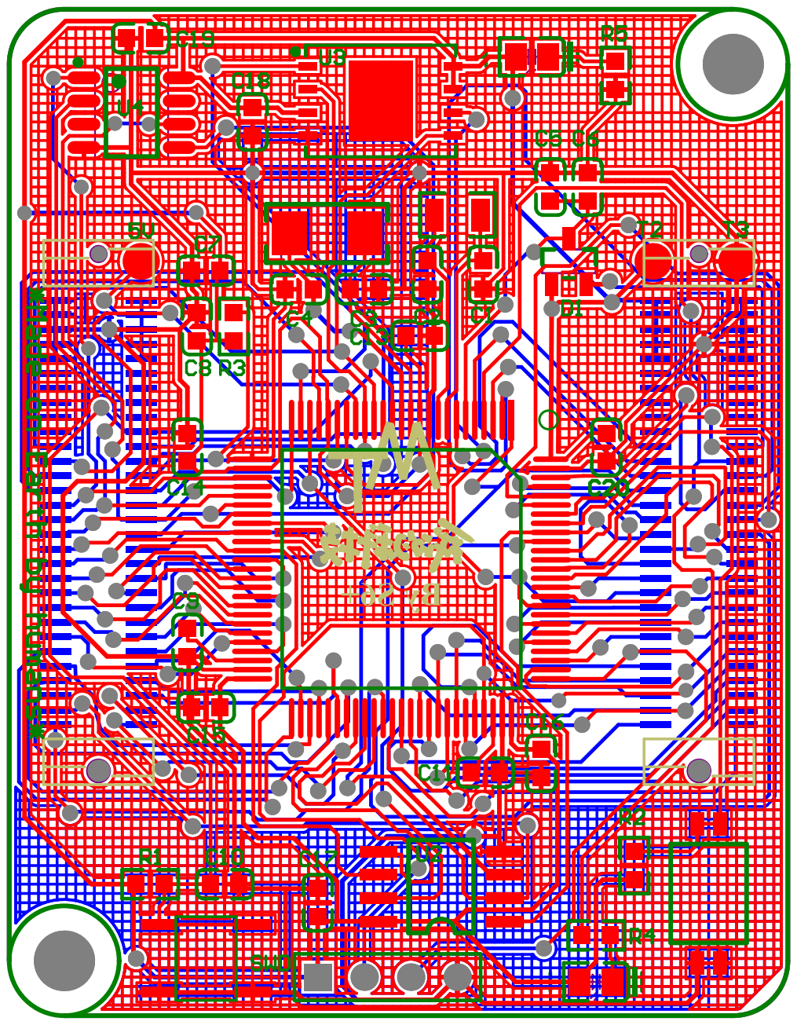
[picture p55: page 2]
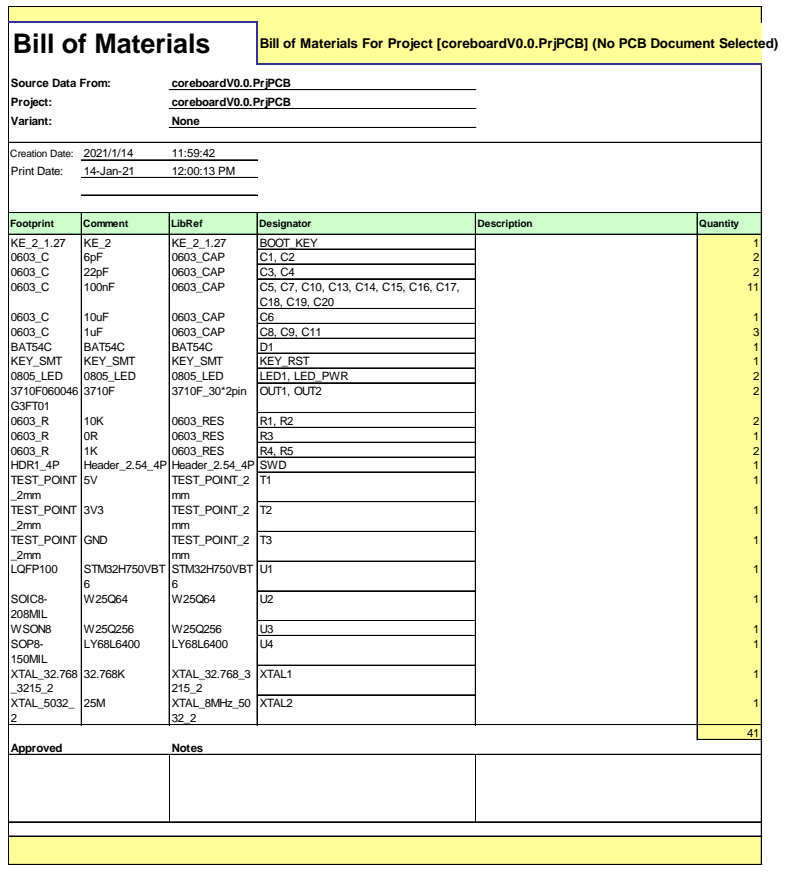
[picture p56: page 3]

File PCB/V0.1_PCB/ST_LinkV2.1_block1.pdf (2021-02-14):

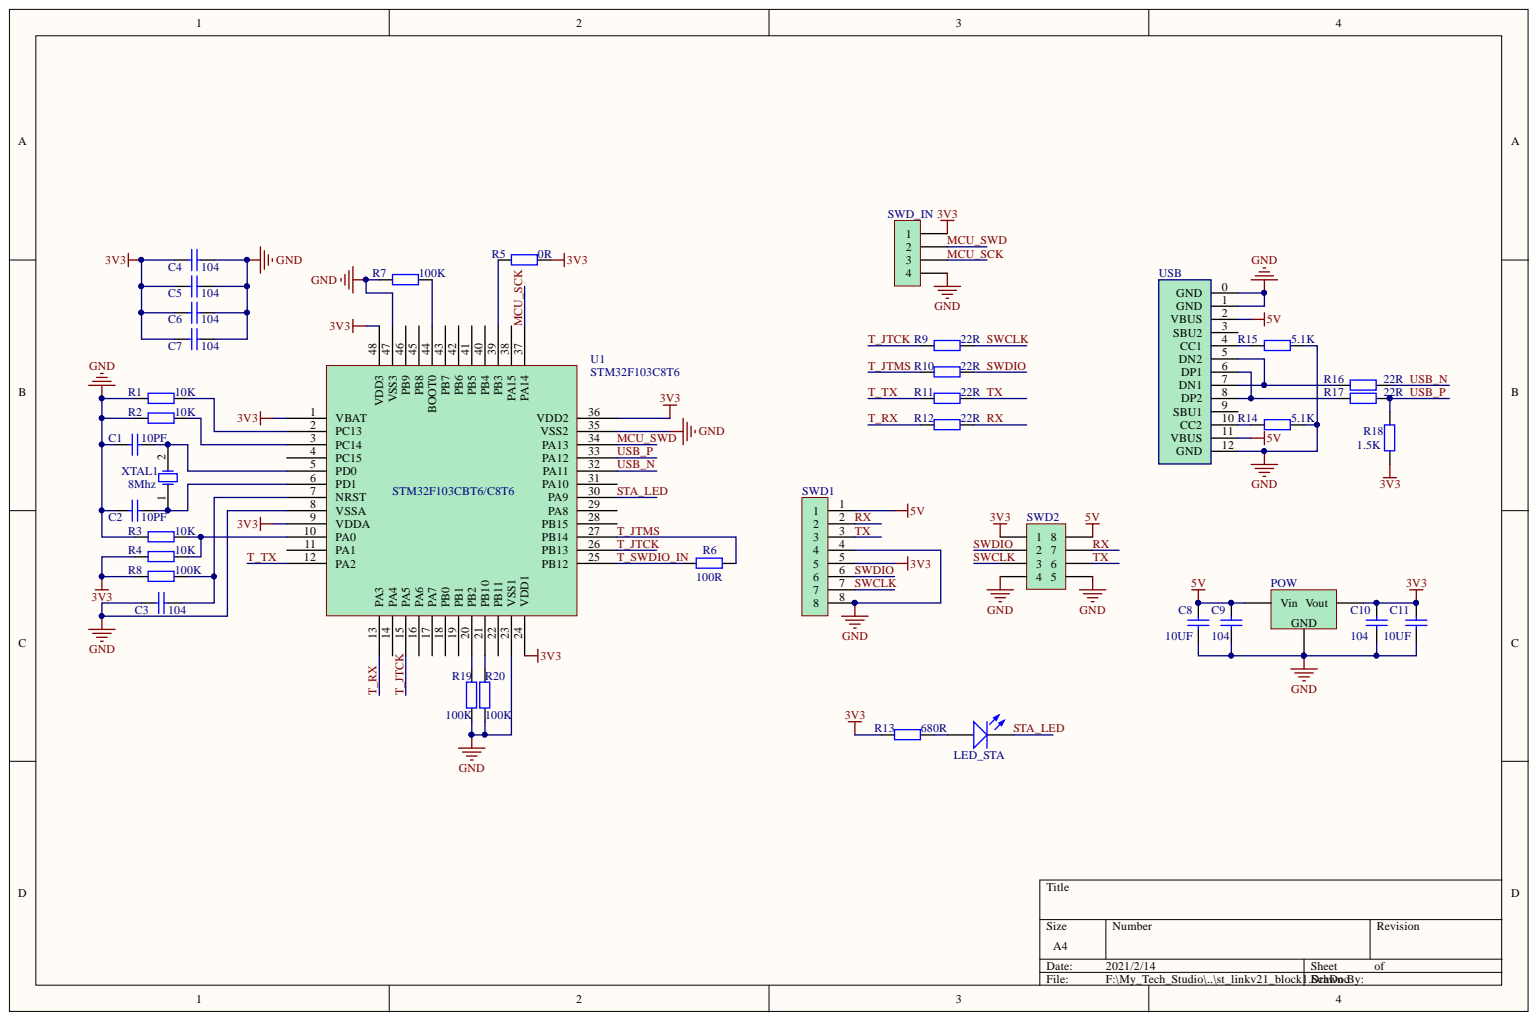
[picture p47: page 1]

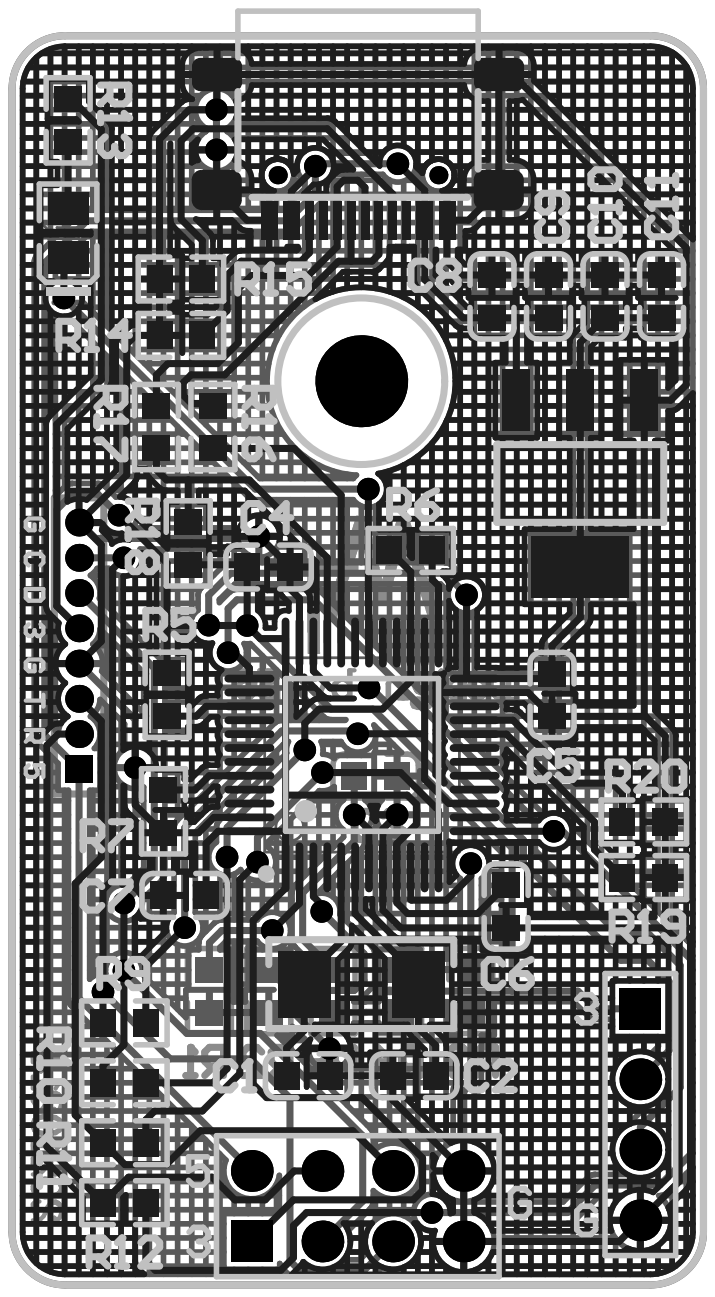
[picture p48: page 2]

Bill of Materials | Bill of Materials For Project [st_linkv21_block1.PrjPCB] (No PCB Document Selected)
Source Data From: | st_linkv21_block1.PrjPCB
Project: | | st_linkv21_block1.PrjPCB
Variant: | | None
Creation Date: 2021/2/14 | 14:26:55
Print Date: | 14-Feb-21 | 2:27:29 PM
Footprint | Comment | LibRef | Designator | Description | Quantity
0603_C | 10PF | 0603_CAP | C1, C2 | 2
0603_C | 104 | 0603_CAP | C3, C4, C5, C6, C7, C9, C10 | 7
0603_C | 10UF | 0603_CAP | C8, C11 | 2
0805_LED | 0805_LED | 0805_LED | LED_STA | 1
SOT223 | AMS1117_3.3 | AMS1117_3.3 | POW | 1
0603_R | 10K | 0603_RES | R1, R2, R3, R4 | 4
0603_R | 0R | 0603_RES | R5 | 1
0603_R | 100R | 0603_RES | R6 | 1
0603_R | 100K | 0603_RES | R7, R8, R19, R20 | 4
0603_R | 22R | 0603_RES | R9, R10, R11, R12, R16, R17 | 6
0603_R | 680R | 0603_RES | R13 | 1
0603_R | 5.1K | 0603_RES | R14, R15 | 2
0603_R | 1.5K | 0603_RES | R18 | 1
HDR1.27_8P | Header_1.27_8P | Header_1.27_8P | SWD1 | 1
HDR2_4P | Header_2.54_4p
_2

Header_2.54_4p
_2
SWD2 | 1
HDR1_4P | Header_2.54 | Header_2.54_4P | SWD_IN | 1
LQFP48 | STM32F103C8T
6

STM32F103C8T
6
U1 | | 1
USB | | 1
XTAL1 | | 1
Approved Notes | 39

USB_C_16PI
N_SMT

USB_C_16P_S
MT

USB_C_16P_S
MT
XTAL_5032_
2
8Mhz | XTAL_8MHz_50 32_2

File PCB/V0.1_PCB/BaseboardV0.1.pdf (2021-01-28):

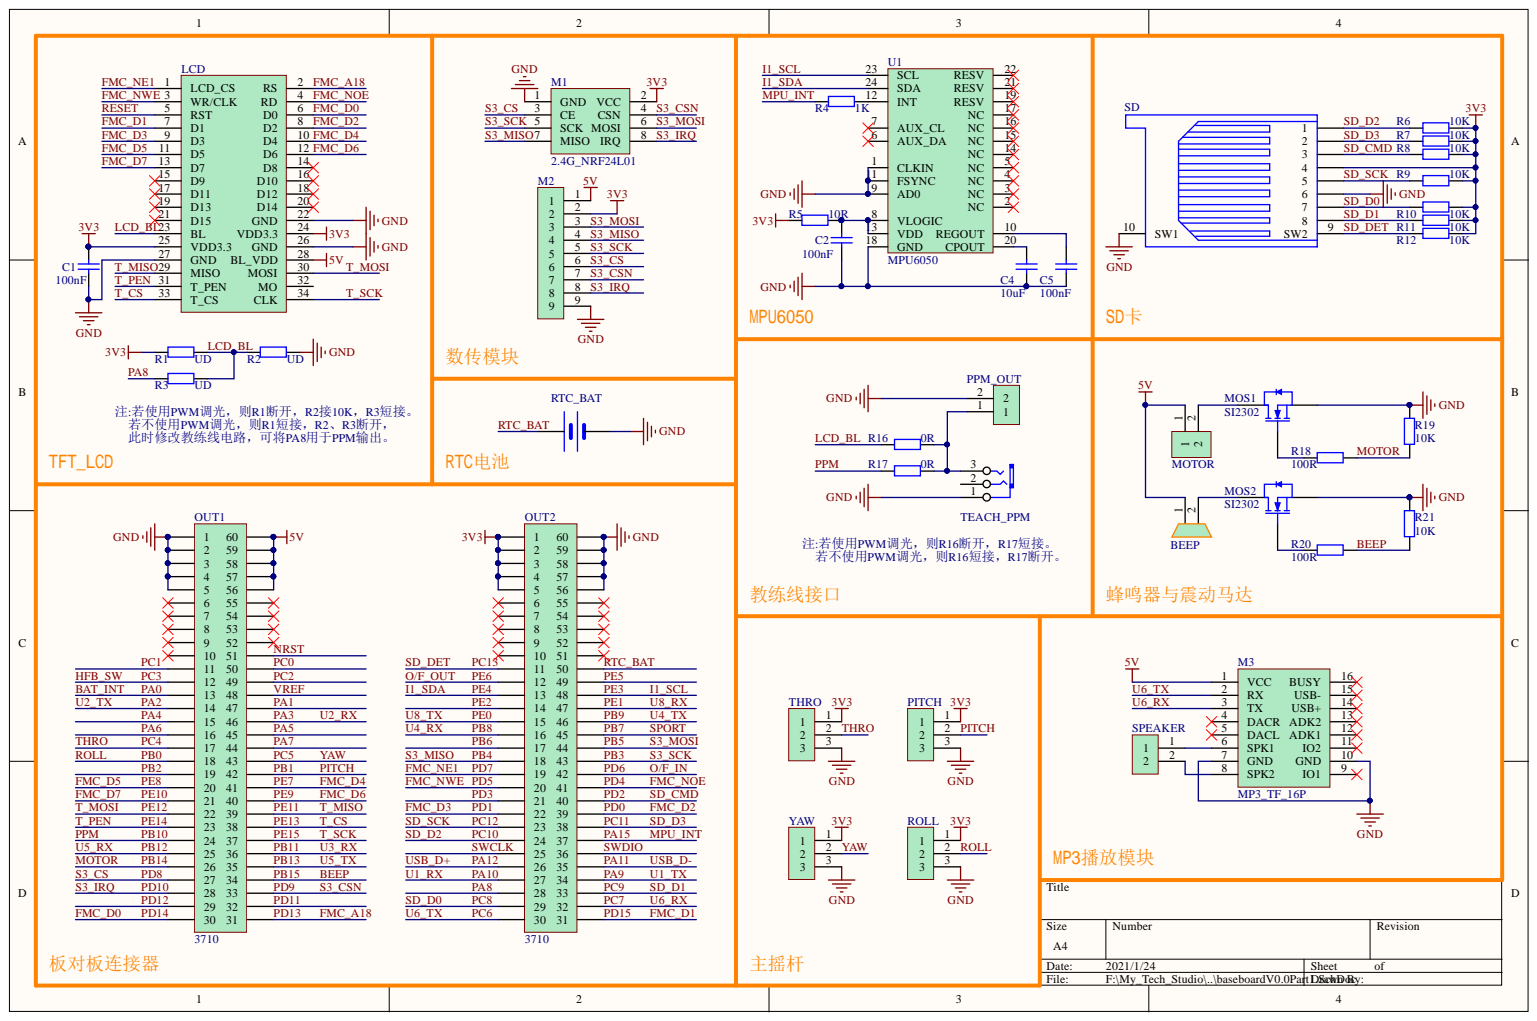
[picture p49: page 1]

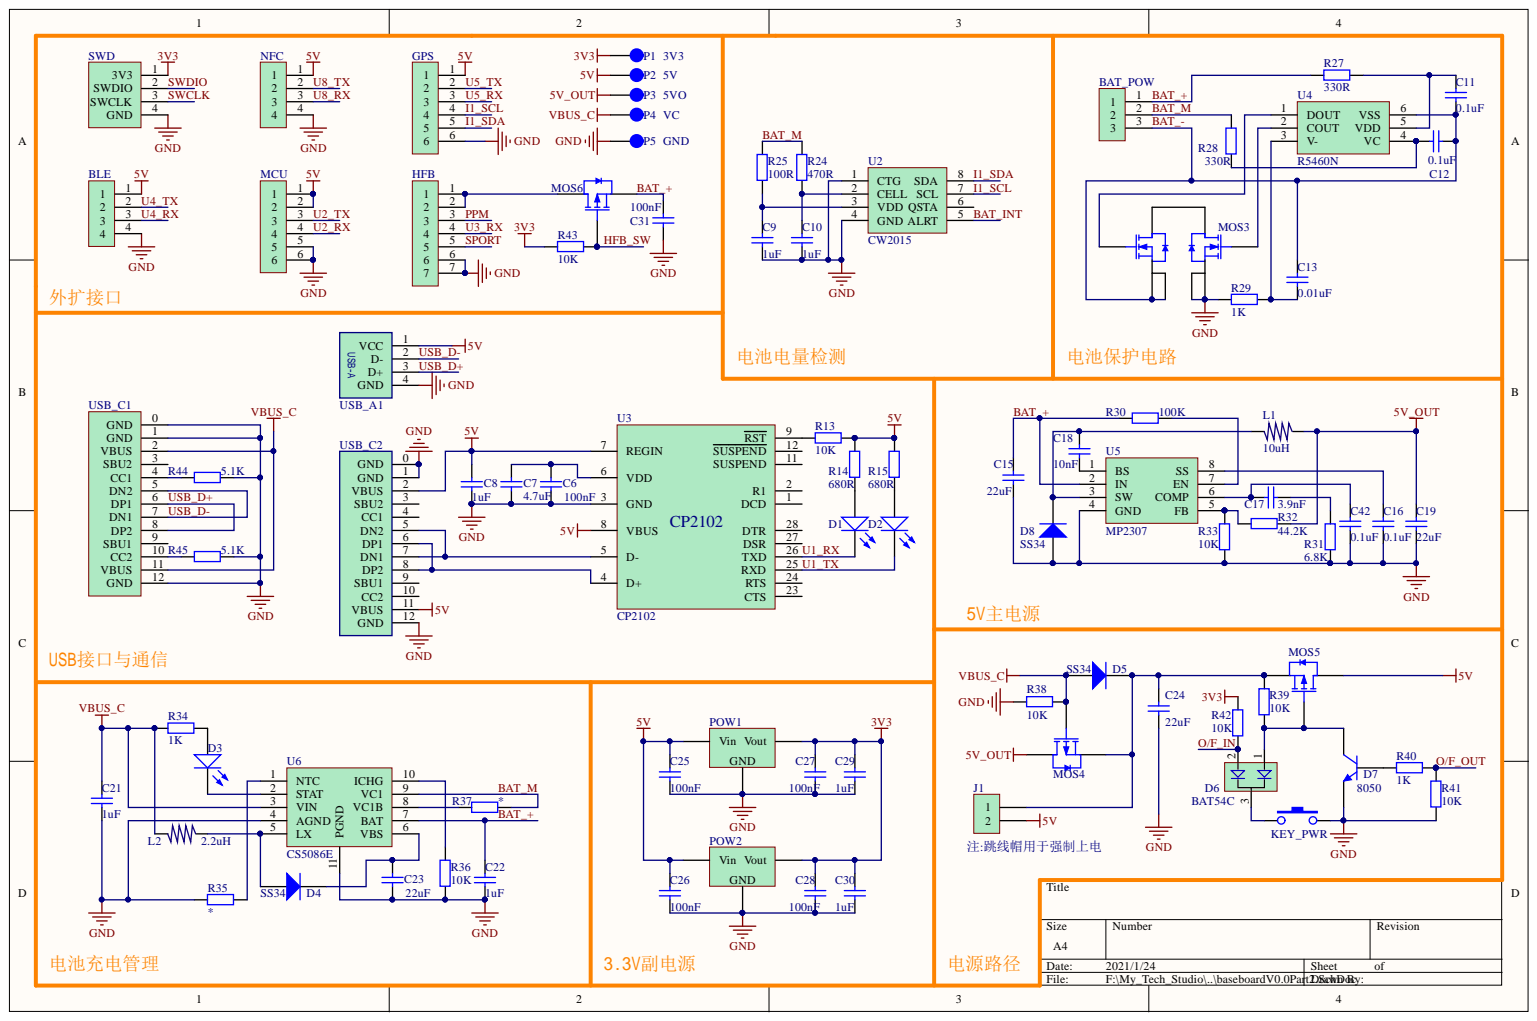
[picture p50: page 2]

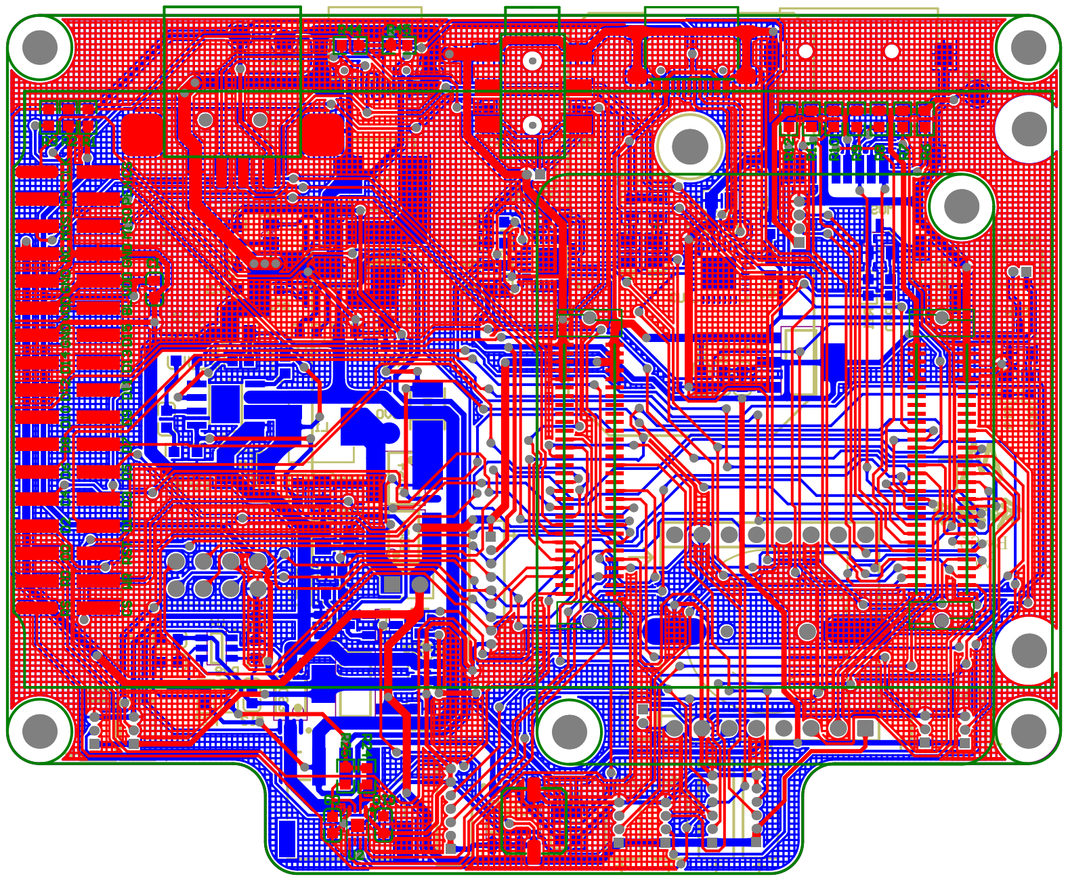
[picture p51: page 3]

Bill of Materials | Bill of Materials For Project [baseboardV0.0.PrjPCB] (No PCB Document Selected)
Source Data From: | baseboardV0.0.PrjPCB
Project: | | baseboardV0.0.PrjPCB
Variant: | | None
Creation Date: 2021/1/24 | 21:10:37
Print Date: | 24-Jan-21 | 9:11:41 PM
Footprint | Comment | LibRef | Designator | Description | Quantity
| | | BAT_POW | | 1
| | | BEEP | | 1

XH2.54_3P_
SMT_L

XH2.54_3P_SM
T_T

XH2.54_3P_SM
T_T
BEEP_5020_
SMT

BEEP_5020_SM
T

BEEP_5020_SM
T
SH1.25MM_4
P
| SH1.25mm_4P | SH1.25mm_4P | BLE, NFC | | 2
0603_C | 100nF | 0603_CAP | C1, C2, C5, C6, C25, C26, C27, C28, C31 | | 9
0603_C | 10uF | 0603_CAP | C4 | | 1
0805_C | 4.7uF | 0805_CAP | C7 | | 1
0603_C | 1uF | 0603_CAP | C8, C9, C10, C21, C22, C29, C30 | | 7
0603_C | 0.1uF | 0603_CAP | C11, C12, C16, C42 | | 4
0603_C | 0.01uF | 0603_CAP | C13 | | 1
0805_C | 22uF | 0805_CAP | C15, C19, C23, C24 | | 4
0603_C | 3.9nF | 0603_CAP | C17 | | 1
0603_C | 10nF | 0603_CAP | C18 | | 1
0805_LED | 0805_LED | 0805_LED | D1, D2, D3 | | 3
DO214_SMC | SS34 | SS34_DO214 | D4, D5, D8 | | 3
BAT54C | BAT54C | BAT54C | D6 | | 1
SOT23 | 8050 | NPN_SS8050_S
| | OT23 | D7 | | 1
SH1.25MM_6 P | SH1.25mm_6P | SH1.25mm_6P | GPS, MCU | | 2
SH1.25MM_7 P | SH1.25mm_7P | SH1.25mm_7P | HFB | | 1
HDR1_2P | Header_2.54_2P | Header_2.54_2P | J1 | | 1
KEY_S_6*6 | KEY_S_6*6 | KEY_S_6*6 | KEY_PWR | | 1
0630_L | 10uH | 0630_L | L1 | | 1
0630_L | 2.2uH | 0630_L | L2 | | 1
LCD_3.5_480 *320_SMT | LCD_3.5_480*3
| 20_SMT | LCD_3.5_480*3
| | 20_SMT | LCD | | 1
2.4G_NRF24 L01 | 2.4G_NRF24L01 | 2.4G_NRF24L01 | M1 | | 1
SH1.25MM_9 P | SH1.25mm_9P | SH1.25mm_9P | M2 | | 1
MP3_TF_16P | MP3_TF_16P | MP3_TF_16P | M3 | | 1
SOT23 | SI2302 | MOSN_SI2302_
| | SOT23 | MOS1, MOS2 | | 2
TSSOP-8 | MOSN_8205A_T
| SSOP8 | MOSN_8205A_T
| | SSOP8 | MOS3 | | 1
SOIC8_MOS | MOSP_AO4419
| _SOIC8 | MOSP_AO4419
| | _SOIC8 | MOS4, MOS5, MOS6 | | 3
SH1.25mm_2 P | SH1.25mm_2P | SH1.25mm_2P | MOTOR, PPM_OUT, SPEAKER | | 3
MT_SWD_1 | SWD | MT_SWD_1 | MTSWD | | 1
3710F060046 G3FT01 | 3710 | 3710F_30*2pin | OUT1, OUT2 | | 2
TEST_POINT _2mm | 3V3 | TEST_POINT_2
| | mm | P1 | | 1
TEST_POINT _2mm | 5V | TEST_POINT_2
| | mm | P2 | | 1
TEST_POINT _2mm | 5VO | TEST_POINT_2
| | mm | P3 | | 1
TEST_POINT _2mm | VC | TEST_POINT_2
| | mm | P4 | | 1
TEST_POINT _2mm | GND | TEST_POINT_2
| | mm | P5 | | 1
SH1.25mm_3 P | pitch | SH1.25mm_3P | PITCH | | 1
SOT223 | AMS1117_3.3 | AMS1117_3.3 | POW1, POW2 | | 2
0603_R | UD | 0603_RES | R1, R2, R3 | | 3
0603_R | 1K | 0603_RES | R4, R29, R34, R40 | | 4
0603_R | 10R | 0603_RES | R5 | | 1
0603_R | 10K | 0603_RES | R6, R7, R8, R9, R10, R11, R12, R13, R19,
| | | R21, R33, R36, R38, R39, R41, R42, R43 | | 17
0603_R | 680R | 0603_RES | R14, R15 | | 2
0603_R | 0R | 0603_RES | R16, R17 | | 2
0603_R | 100R | 0603_RES | R18, R20, R25 | | 3
0603_R | 470R | 0603_RES | R24 | | 1
0603_R | 330R | 0603_RES | R27, R28 | | 2
0603_R | 100K | 0603_RES | R30 | | 1
0603_R | 6.8K | 0603_RES | R31 | | 1
0603_R | 44.2K | 0603_RES | R32 | | 1
0603_R | | 0603_RES | R35, R37 | | 2
0603_R | 5.1K | 0603_RES | R44, R45 | | 2
SH1.25mm_3 P | roll | SH1.25mm_3P | ROLL | | 1
CR1220_BAT TERY | CR1220_BATTE
| RY | CR1220_BATTE
| | RY | RTC_BAT | | 1
TF_card | TF_Card | TF_Card | SD | | 1
AUDIO_PJ31 3D | AUDIO_PJ313D | AUDIO_PJ313D | TEACH_PPM | | 1
SH1.25mm_3 P | thro | SH1.25mm_3P | THRO | | 1
QFN24 | MPU6050 | MPU6050 | U1 | | 1
CW2015_TD FN | CW2015 | CW2015_TDFN | U2 | | 1
QFN28 | CP2102 | CP2102_QFN28 | U3 | | 1
SOT_23_6 | R5460N | R5460N | U4 | 2-CELL PROTECTOR | 1
SOIC8N | MP2307 | MP2307 | U5 | | 1
ESOP10L | CS5086E | CS5086E | U6 | | 1
USB_A_SMT | USB_A_SMT | USB_A_SMT | USB_A1 | | 1
USB_C_16PI N_SMT | USB_C_16P_S
| MT | USB_C_16P_S
| | MT | USB_C1, USB_C2 | | 2
SH1.25mm_3 P | yaw | SH1.25mm_3P | YAW | | 1
Approved | Notes

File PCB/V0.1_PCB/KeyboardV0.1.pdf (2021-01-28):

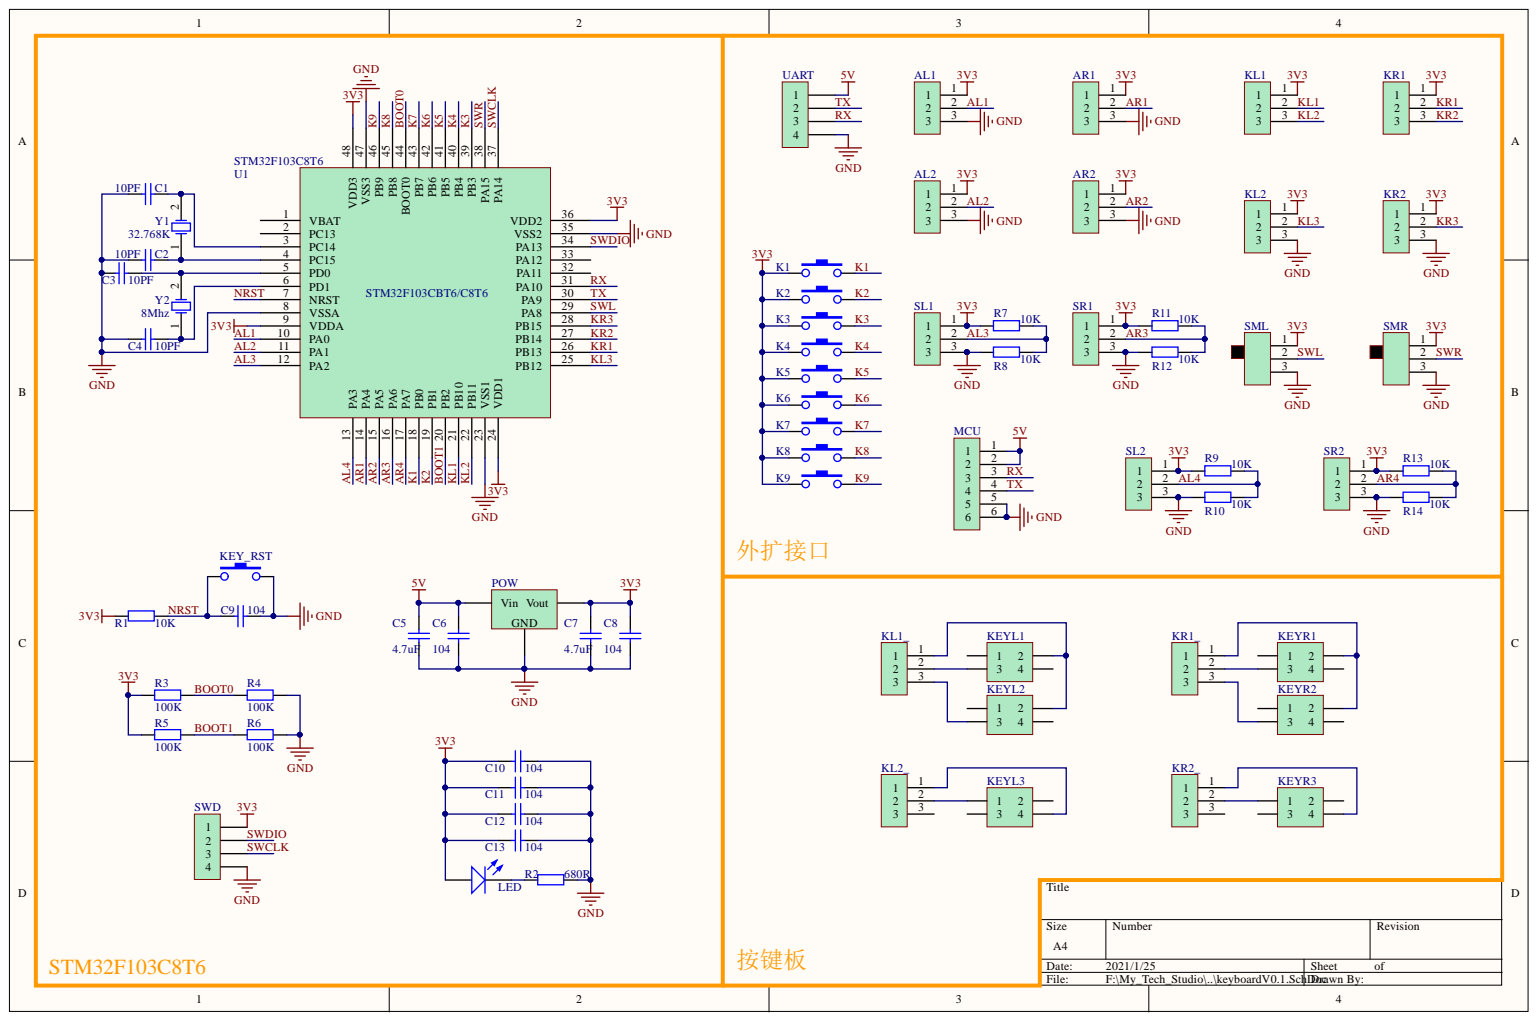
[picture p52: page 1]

NRST | NRST 7 | TX

VSSA 8 | SWL
VDDA 9 | KR3

Size A4 | Number | Revision

Date: 2021/1/25 | Sheet of
File: F:\My_Tech_Studio\..\keyboardV0.1.SchDDorawc n By:

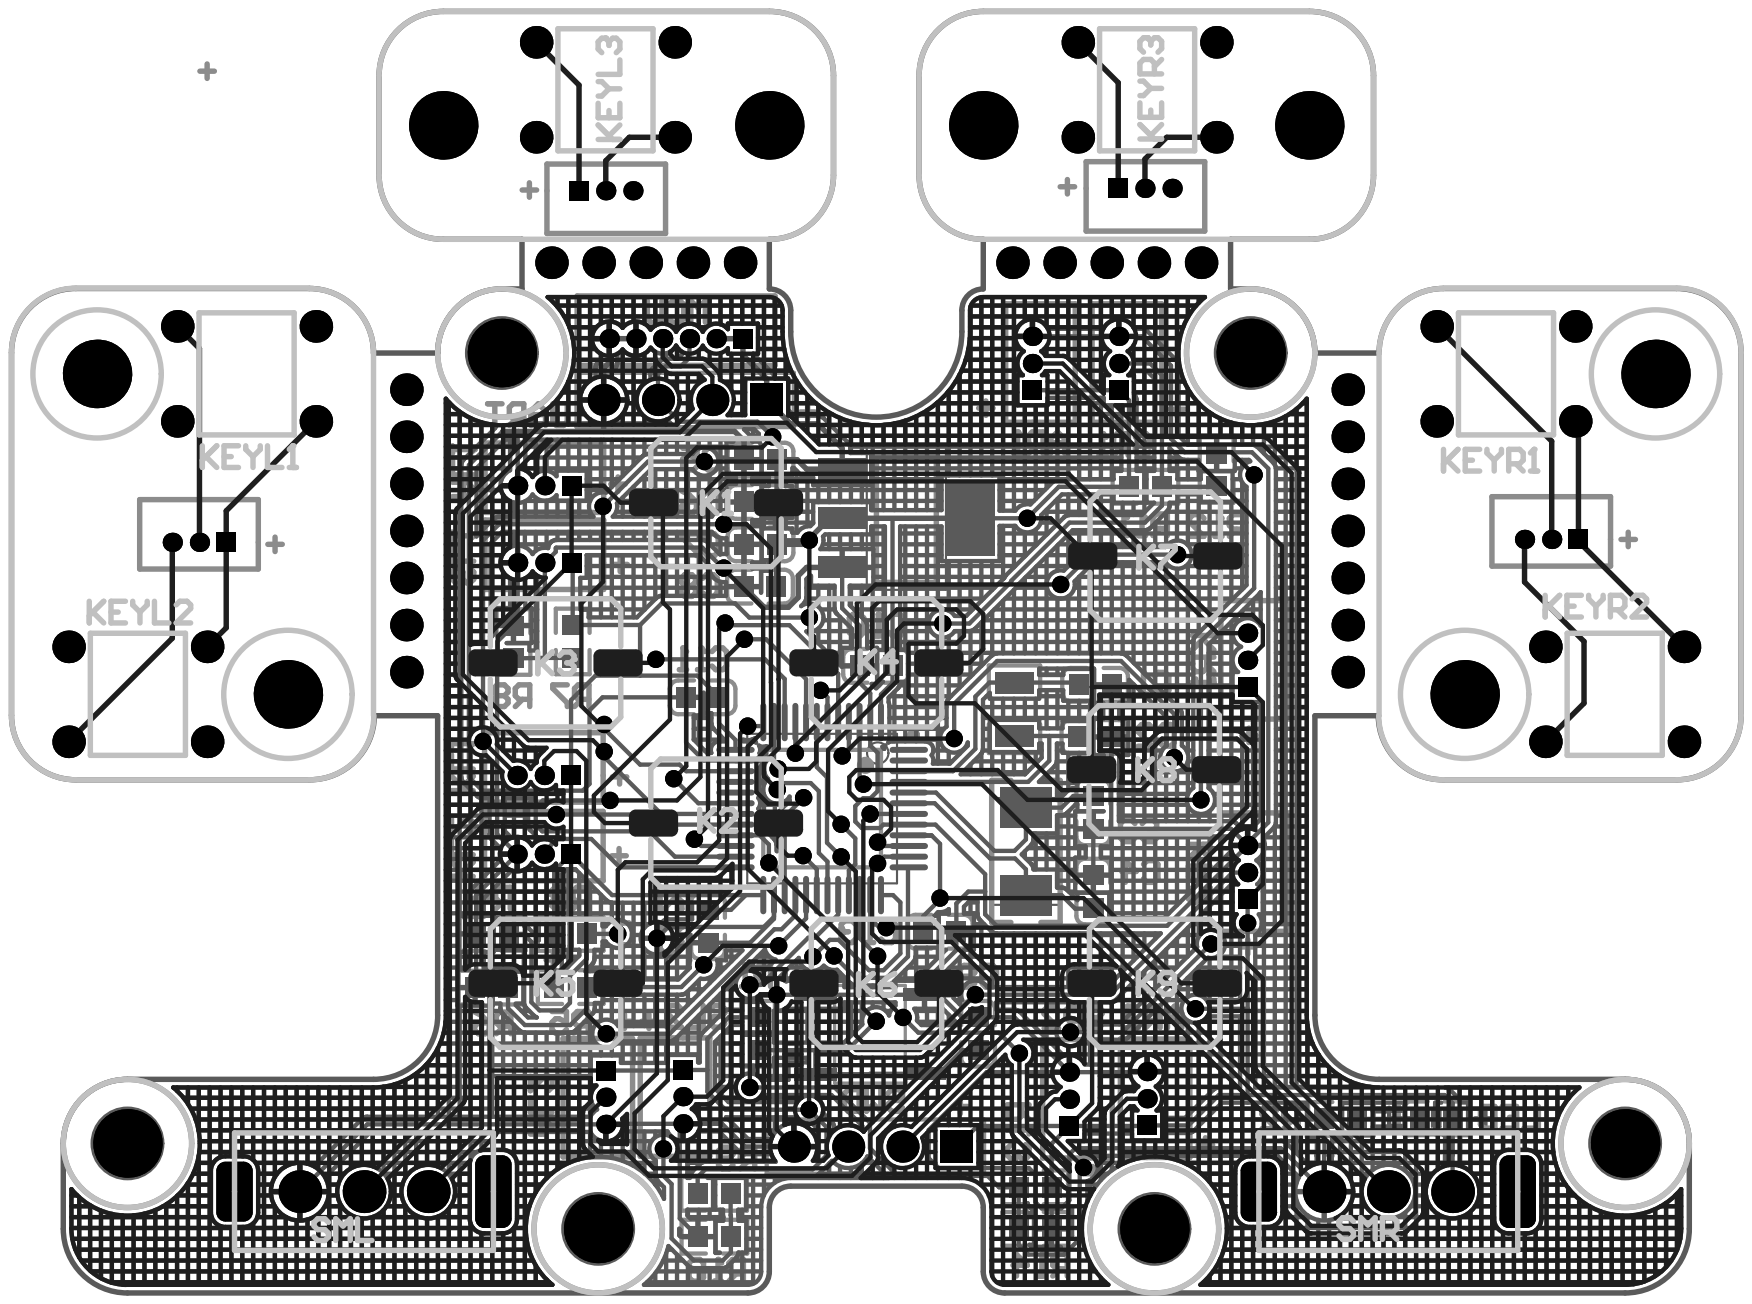
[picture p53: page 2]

Comment | Description | Designator | Footprint | LibRef | Quantity
SH1.25mm_3P | | AL1, AL2, AR1, AR2, KL1, KL1_, KL2, KL2_, KR1, KR1_, KR2, KR2_, SL1, SL2, SR1, SR2 | SH1.25mm_3P | SH1.25mm_3P | 16
10PF | | C1, C2, C3, C4 | 0603_C | 0603_CAP | 4
4.7uF | | C5, C7 | 0603_C | 0603_CAP | 2
104 | | C6, C8, C9, C10, C11, C12, C13 | 0603_C | 0603_CAP | 7
KEY_S_6*6 | | K1, K2, K3, K4, K5, K6, K7, K8, K9 | KEY_S_6*6 | KEY_S_6*6 | 9
KEY_SMT | | KEY_RST | KEY_SMT | KEY_SMT | 1
KEY | | KEYL1, KEYL2, KEYL3, KEYR1, KEYR2, KEYR3 | KEY_6*6 | KEY_6*6 | 6
0603_LED | | LED | 0603_LED | 0603_LED | 1
SH1.25mm_6P | | MCU | SH1.25MM_6P | SH1.25mm_6P | 1
AMS1117_3.3 | | POW | SOT223 | AMS1117_3.3 | 1
10K | | R1, R7, R8, R9, R10, R11, R12, R13, R14 | 0603_R | 0603_RES | 9
680R | | R2 | 0603_R | 0603_RES | 1
100K | | R3, R4, R5, R6 | 0603_R | 0603_RES | 4
SWITCH | | SML, SMR | SWITCH_SS12F44 | SWITCH_SS12F44 | 2
Header_2.54_4P | | SWD, UART | HDR1_4P | Header_2.54_4P | 2
STM32F103C8T6 | | U1 | LQFP48 | STM32F103C8T6 | 1
32.768K | | Y1 | XTAL_32.768_3215_2 | XTAL_32.768_3215_2 | 1
8Mhz | | Y2 | XTAL_5032_2 | XTAL_8MHz_5032_2 | 1

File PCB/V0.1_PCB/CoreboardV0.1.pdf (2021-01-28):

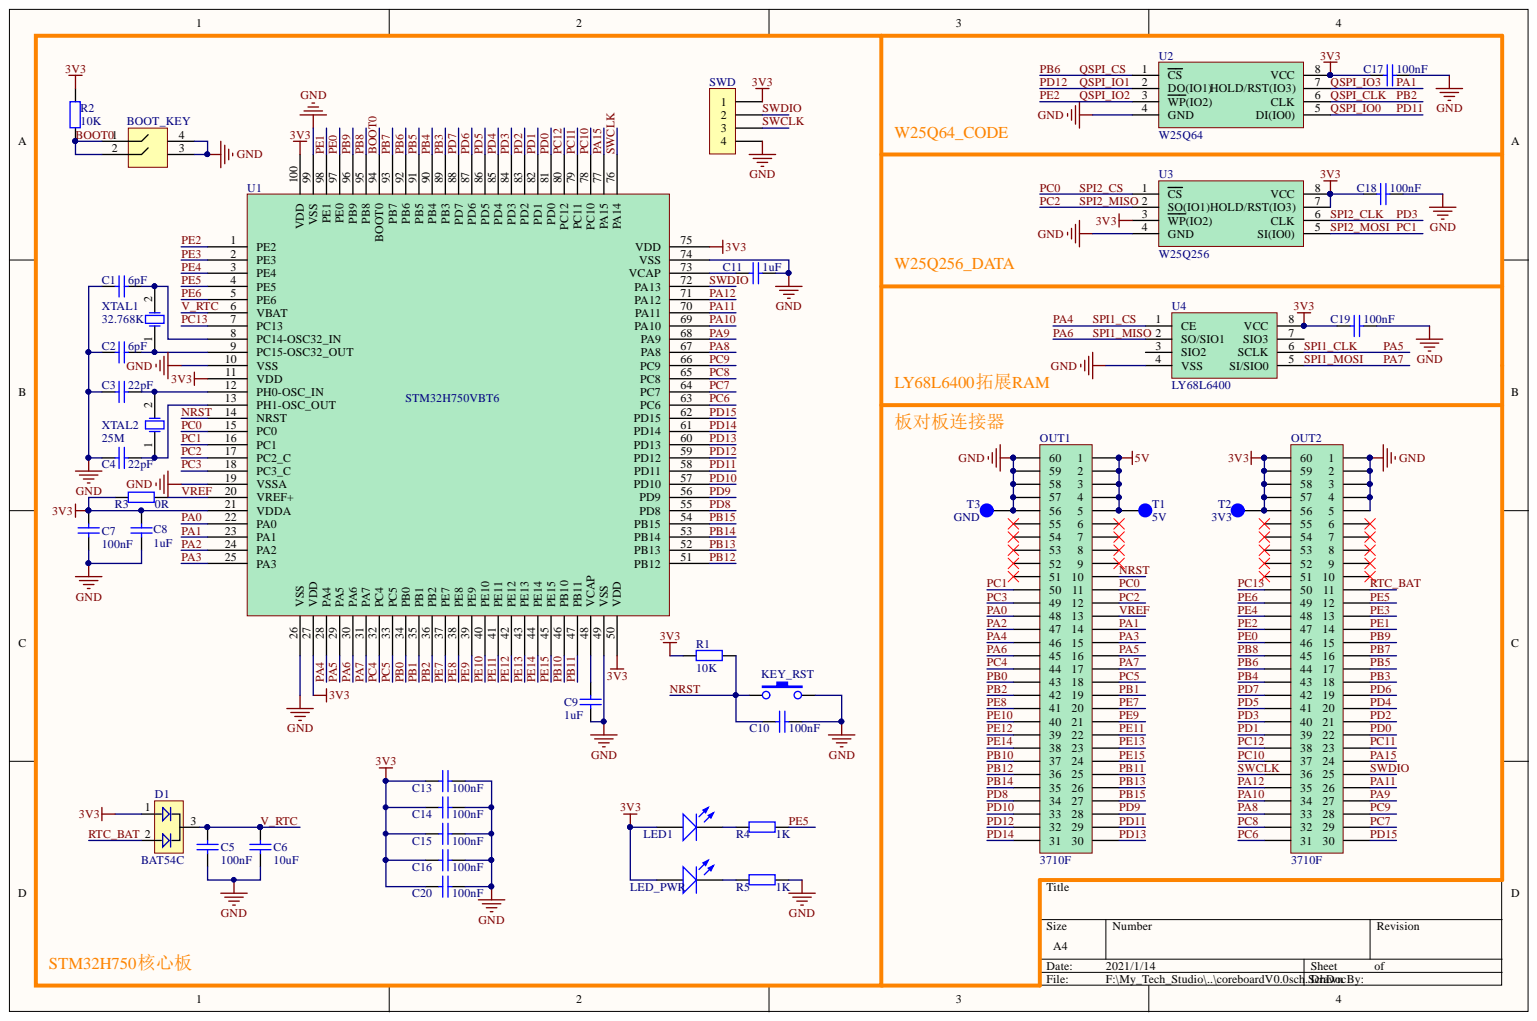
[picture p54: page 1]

VRE F 2 0 | | PD 9

sch.Sch DrawDonc By
